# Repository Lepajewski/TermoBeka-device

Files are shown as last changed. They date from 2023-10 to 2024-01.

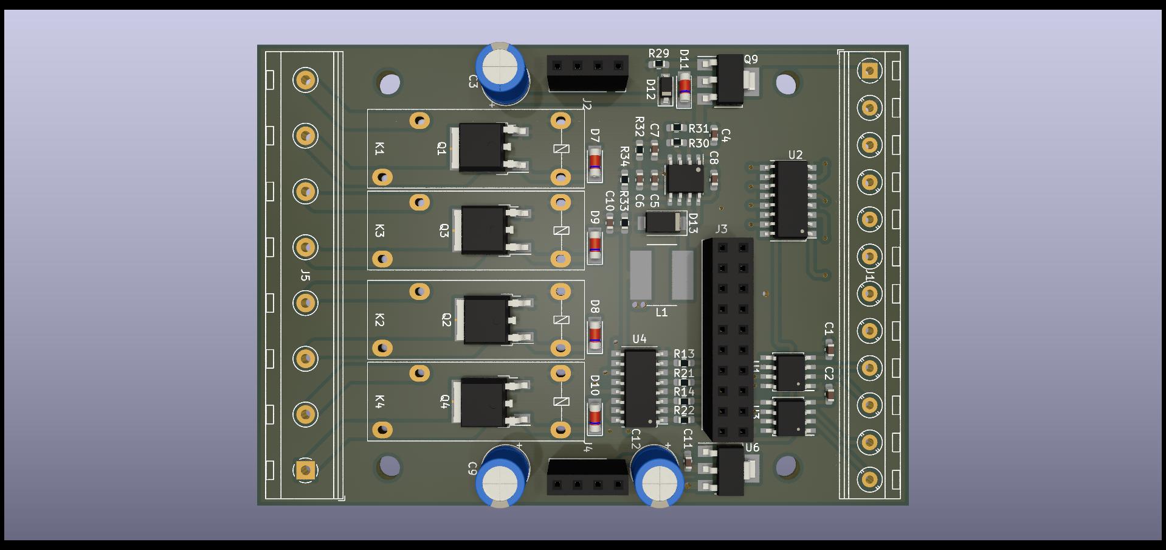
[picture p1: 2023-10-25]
doc/HW/RelayBoard/TermoPLC_RelayBoard.jpg

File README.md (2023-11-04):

# TermoBeka-device

## Installation Guide

### Windows 10

1. Install [Docker Desktop](https://www.docker.com/products/docker-desktop/). Do not check *Enable integration with my default WSL distro* in settings.

2. Install [Remote Development](https://marketplace.visualstudio.com/items?itemName=ms-vscode-remote.vscode-remote-extensionpack) extenstion in VS Code. Do not check *Execute In WSL* in DEV Container: settings

3. Install [Ubuntu 20.04 LTS](https://apps.microsoft.com/store/detail/ubuntu-20046-lts/9MTTCL66CPXJ)
> Note: kernel version must be higher than `5.10.60.1`, check by `uname -a` on Ubuntu or by `wsl --version` on CMD

4. Make Ubuntu default WSL in CMD: `wsl -l -v` and `wsl --set-default Ubuntu-20.04`

5. Install usbipd in CMD: `winget install usbipd`

6. In Ubuntu run commands:
- `sudo apt-get update && sudo apt-get -qqy upgrade`
- `sudo apt install linux-tools-virtual hwdata`
- `sudo update-alternatives --install /usr/local/bin/usbip usbip $(command -v ls /usr/lib/linux-tools/*/usbip | tail -n1) 20`
- `sudo udevadm control --reload`
- `sudo service udev restart`

7. Plug board to computer (on devkit use UART MicroUSB port).

8. In CMD run:
- `usbipd wsl list`
- `usbipd wsl attach --busid id-id`

Now device should be listed as attached:
- `usbipd wsl list`

> Note: more advanced instructions for steps 6-8 available [here](https://github.com/dorssel/usbipd-win/wiki/WSL-support)

9. Open folder in Dev Container:
- first use: `F1` + `Dev Containers: Rebuild Without Cache and Reopen in Container`
- further use: `F1` + `Dev Containers: Reopen in Container`

10. Wait for PlatrofmIO to setup. Reload window after setup.

11. Finally run in terminal:
- `make all`

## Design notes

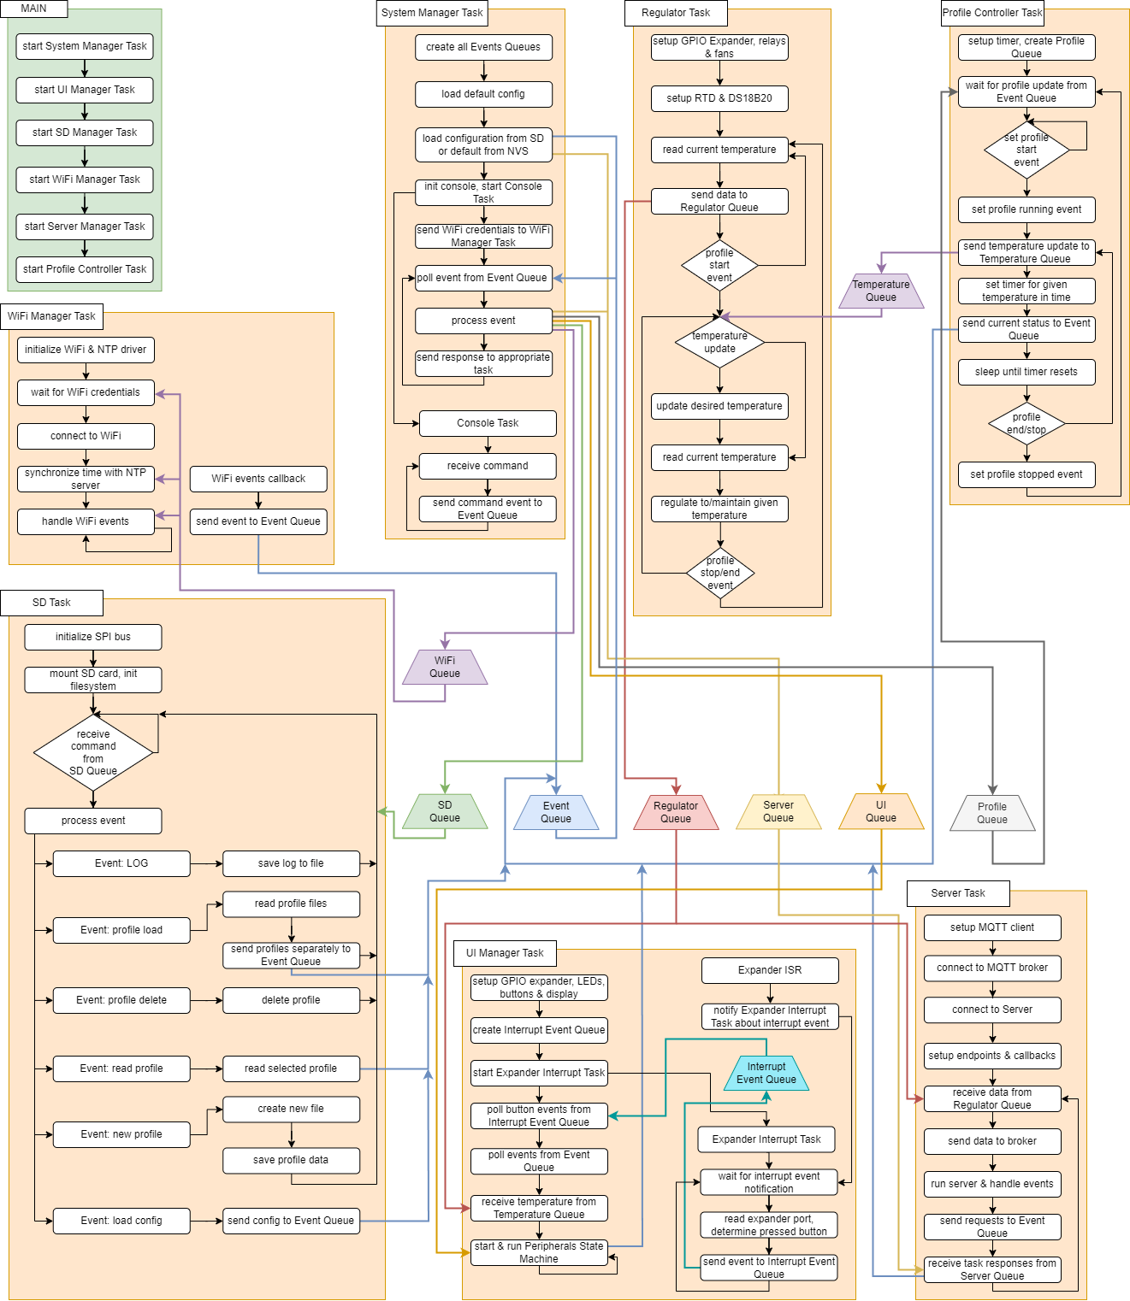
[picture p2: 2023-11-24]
doc/SW/TermoBeka_architecture.png

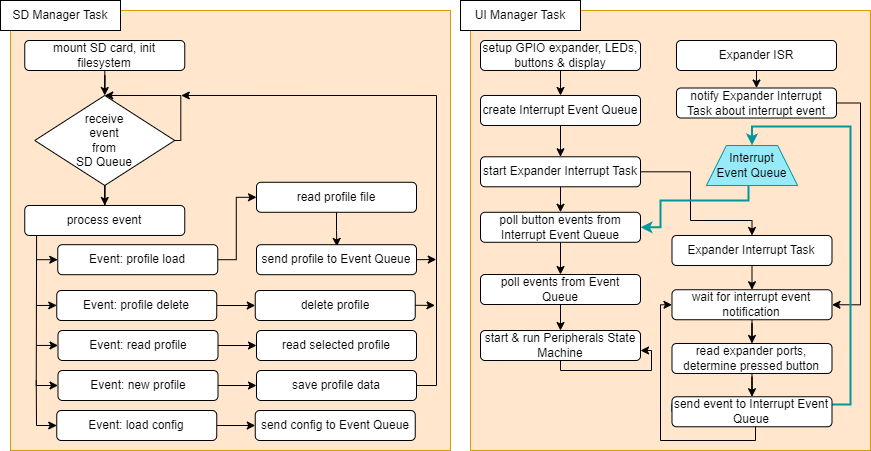
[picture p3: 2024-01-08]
doc/SW/sd_ui.png

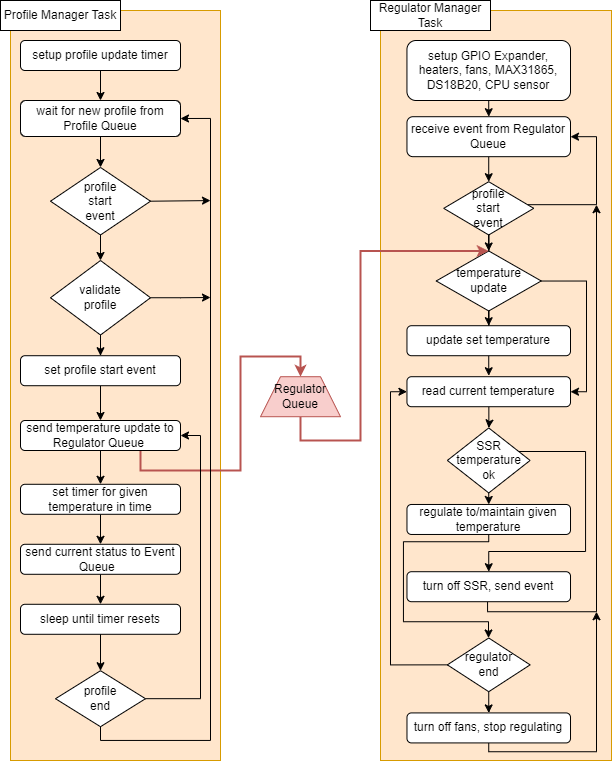
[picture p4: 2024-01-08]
doc/SW/profile_regulator.png

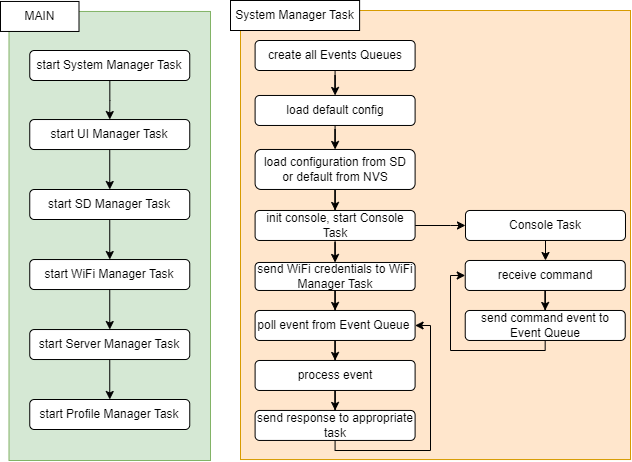
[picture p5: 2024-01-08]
doc/SW/main_sysmgr.png

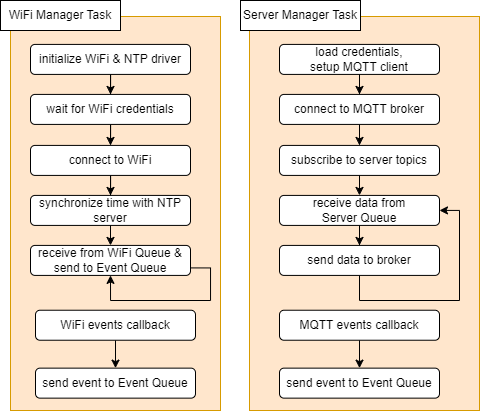
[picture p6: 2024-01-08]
doc/SW/wifi_server.png

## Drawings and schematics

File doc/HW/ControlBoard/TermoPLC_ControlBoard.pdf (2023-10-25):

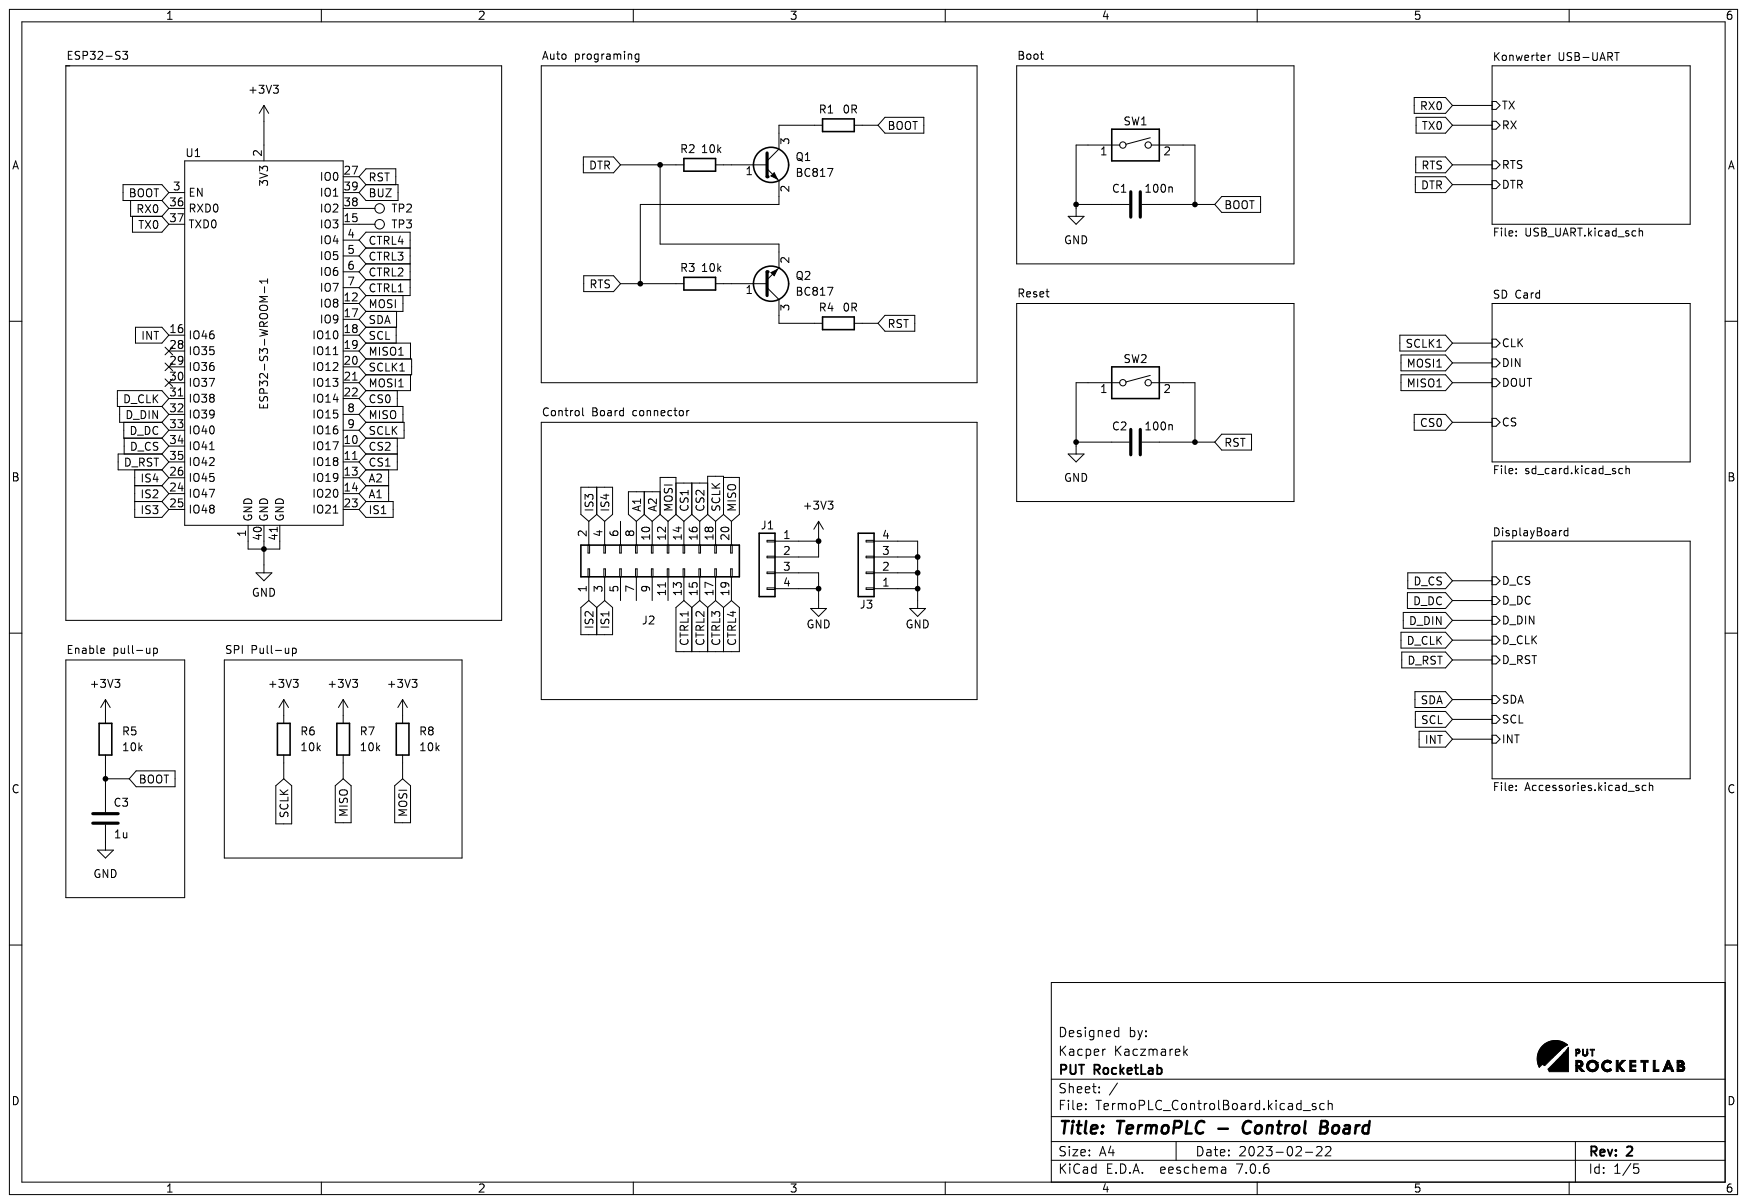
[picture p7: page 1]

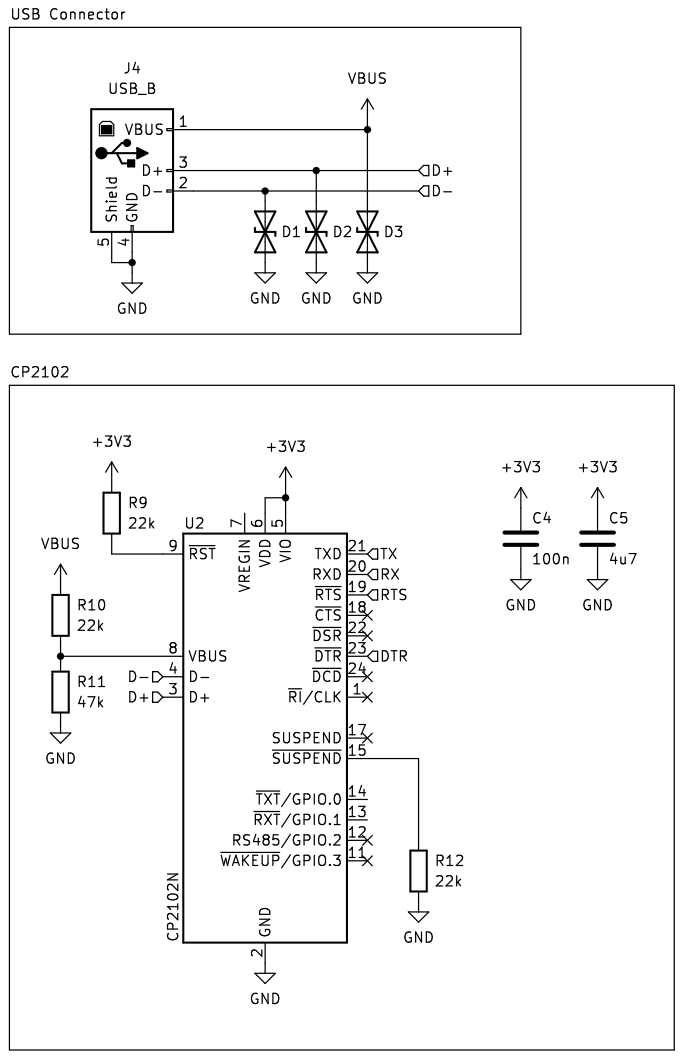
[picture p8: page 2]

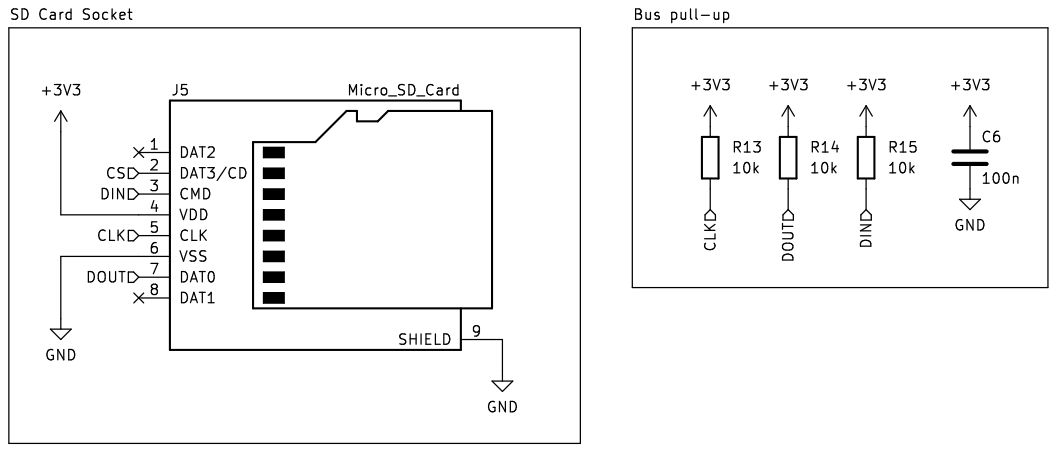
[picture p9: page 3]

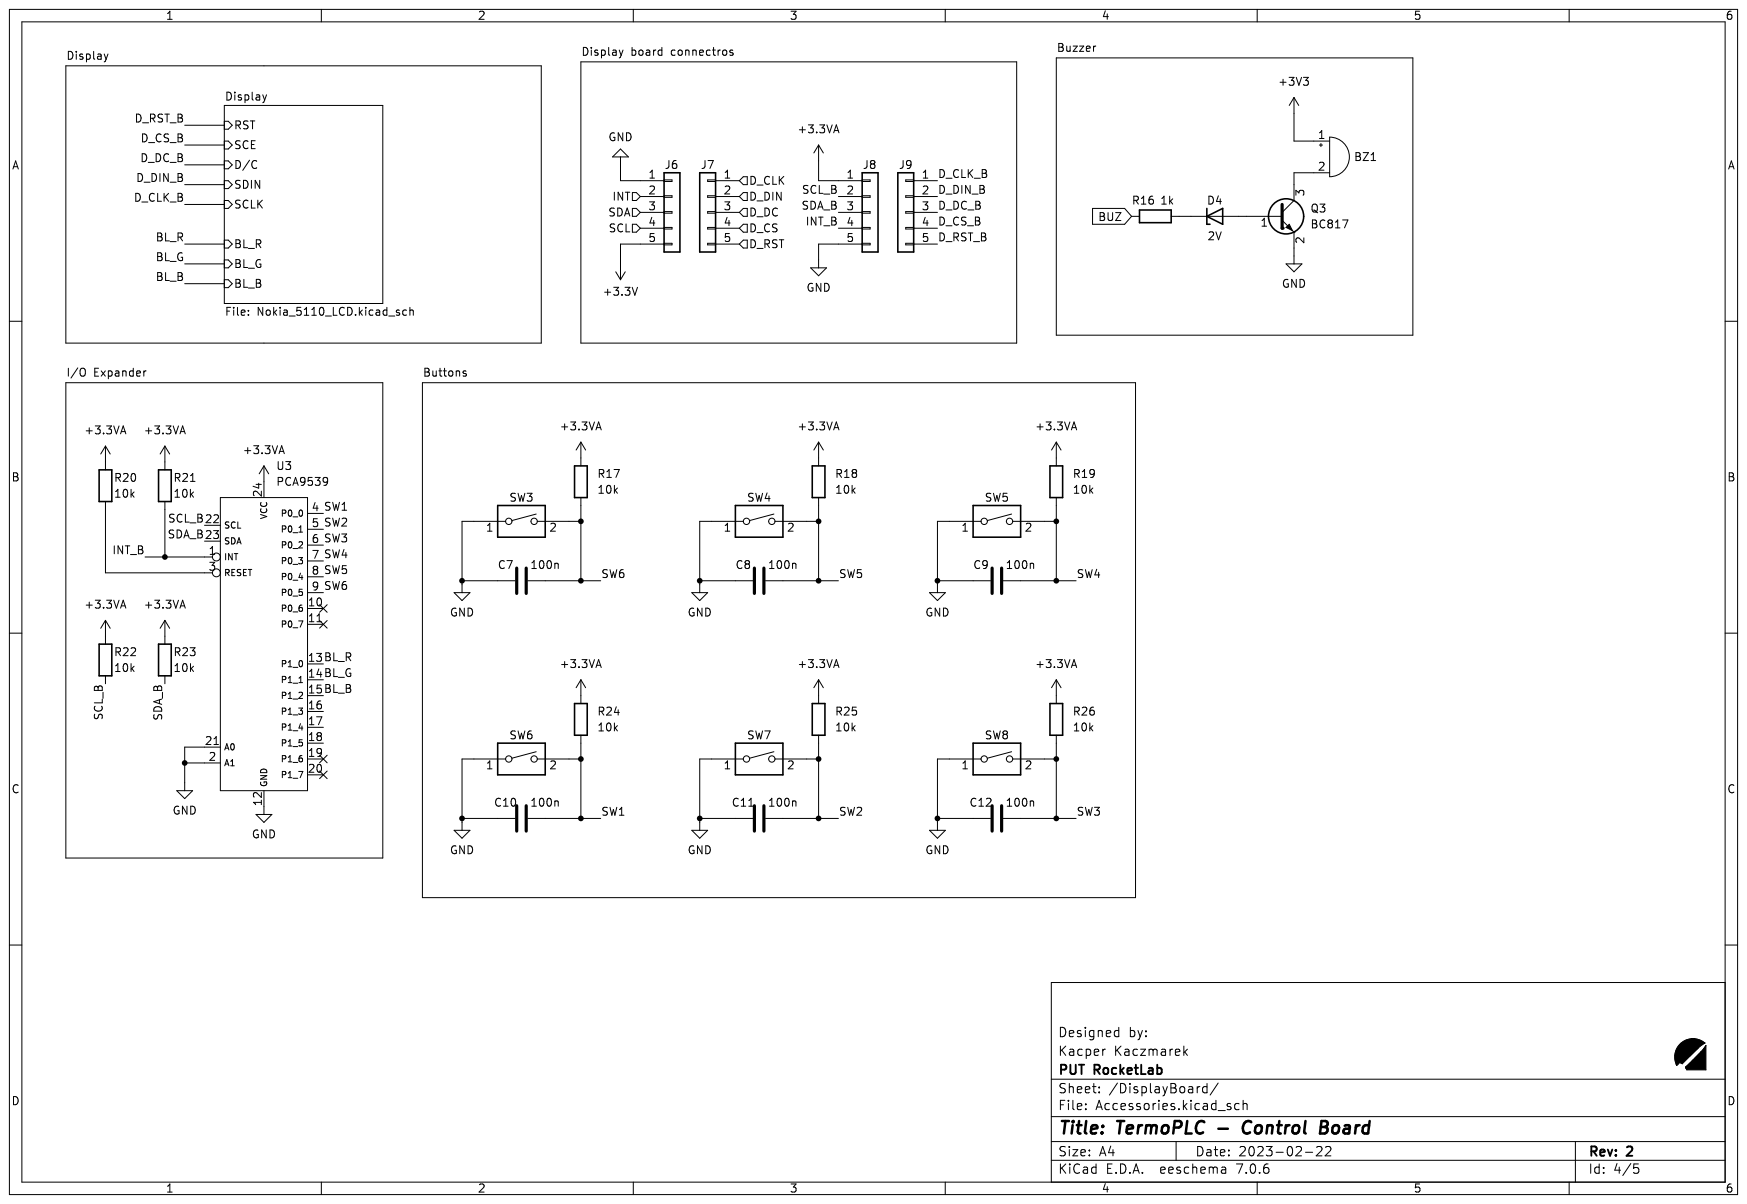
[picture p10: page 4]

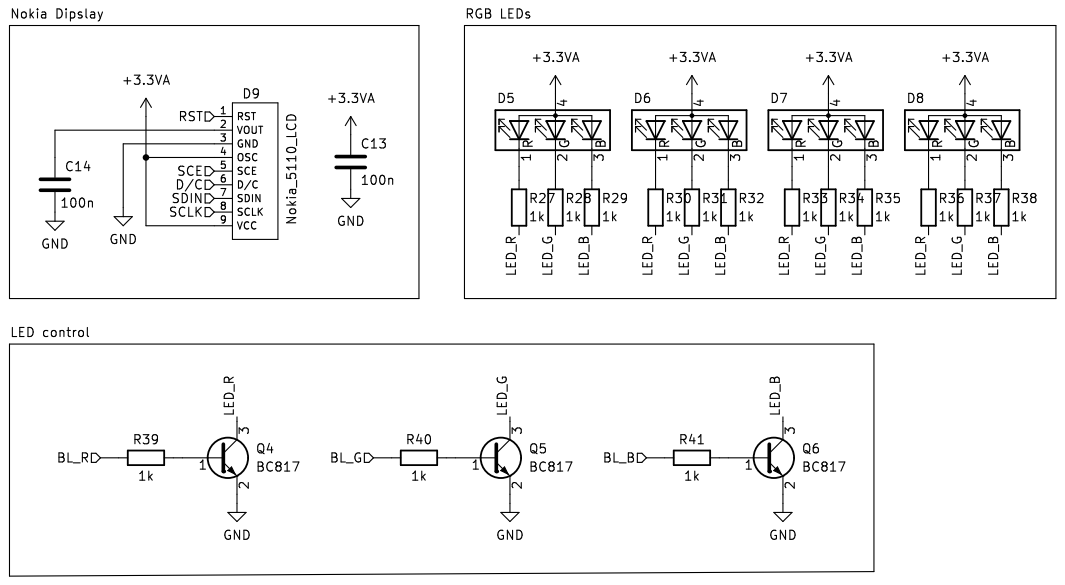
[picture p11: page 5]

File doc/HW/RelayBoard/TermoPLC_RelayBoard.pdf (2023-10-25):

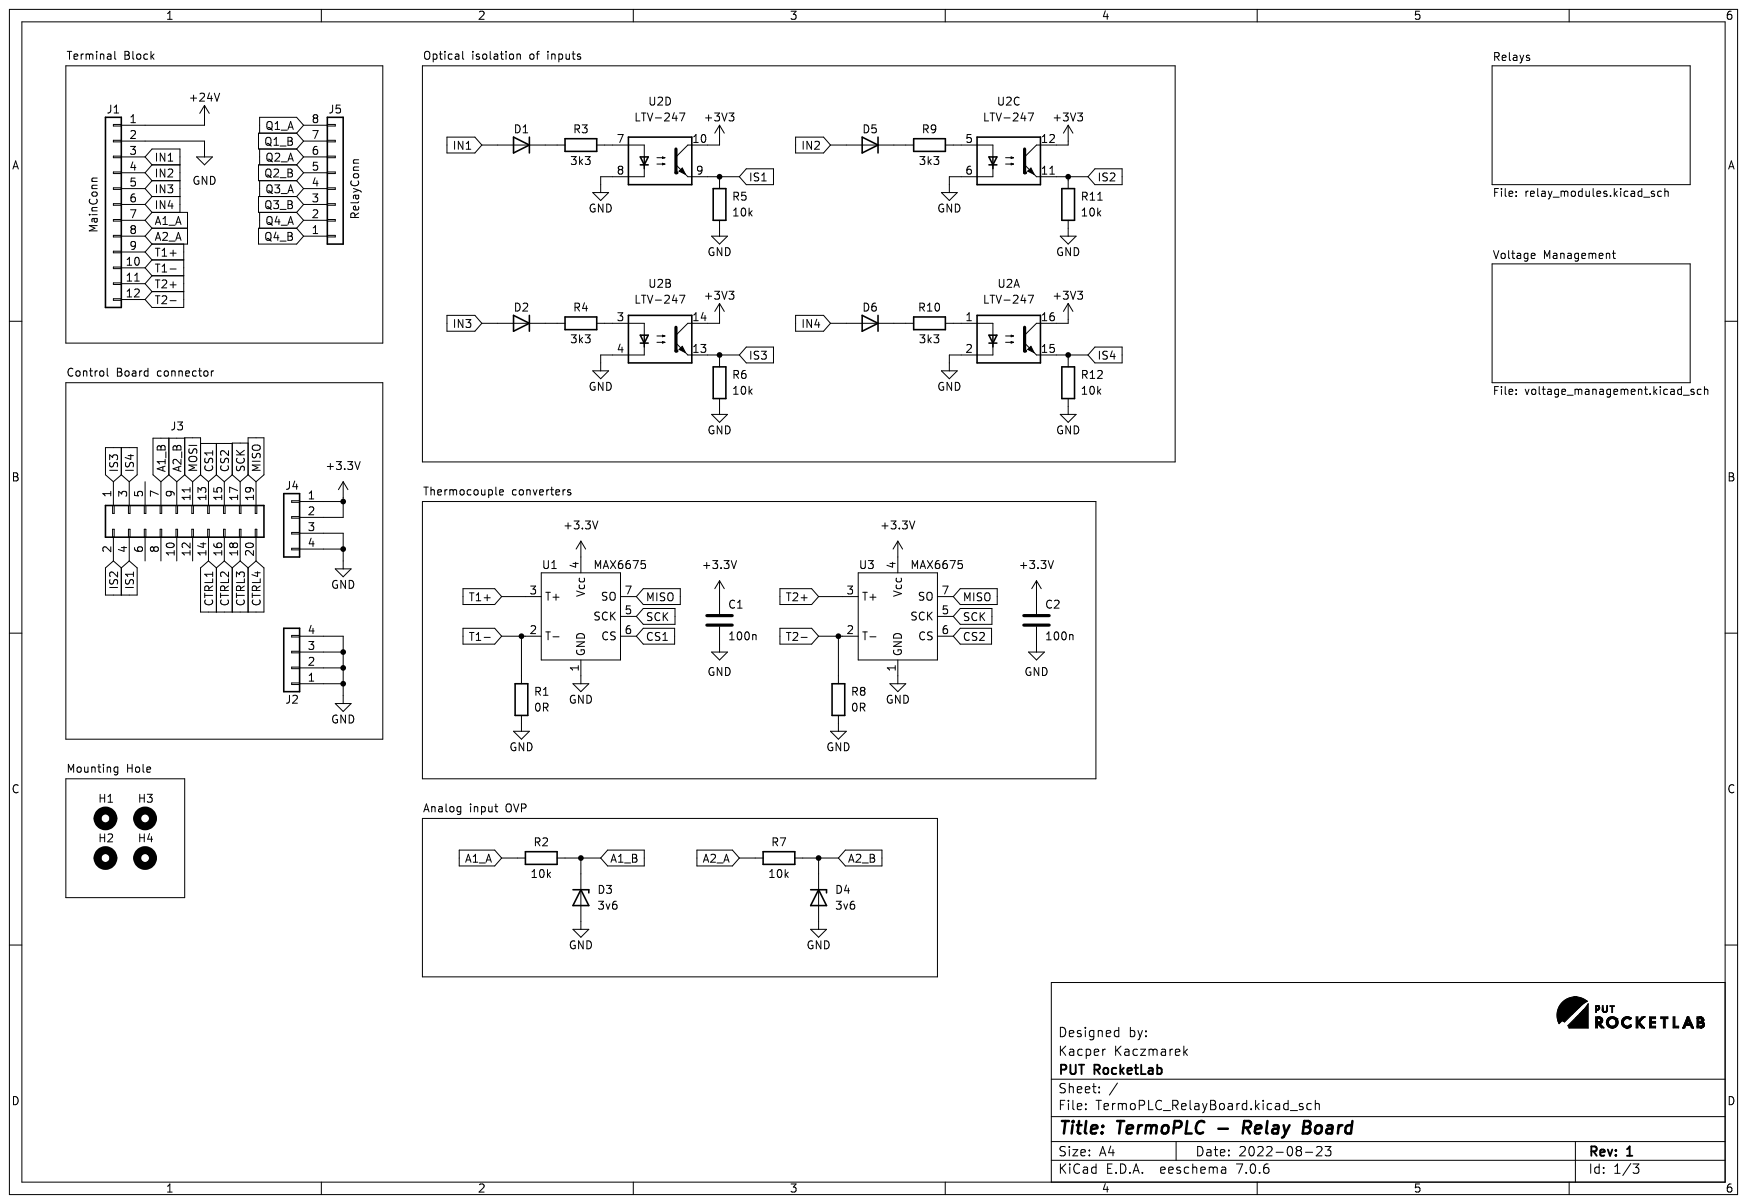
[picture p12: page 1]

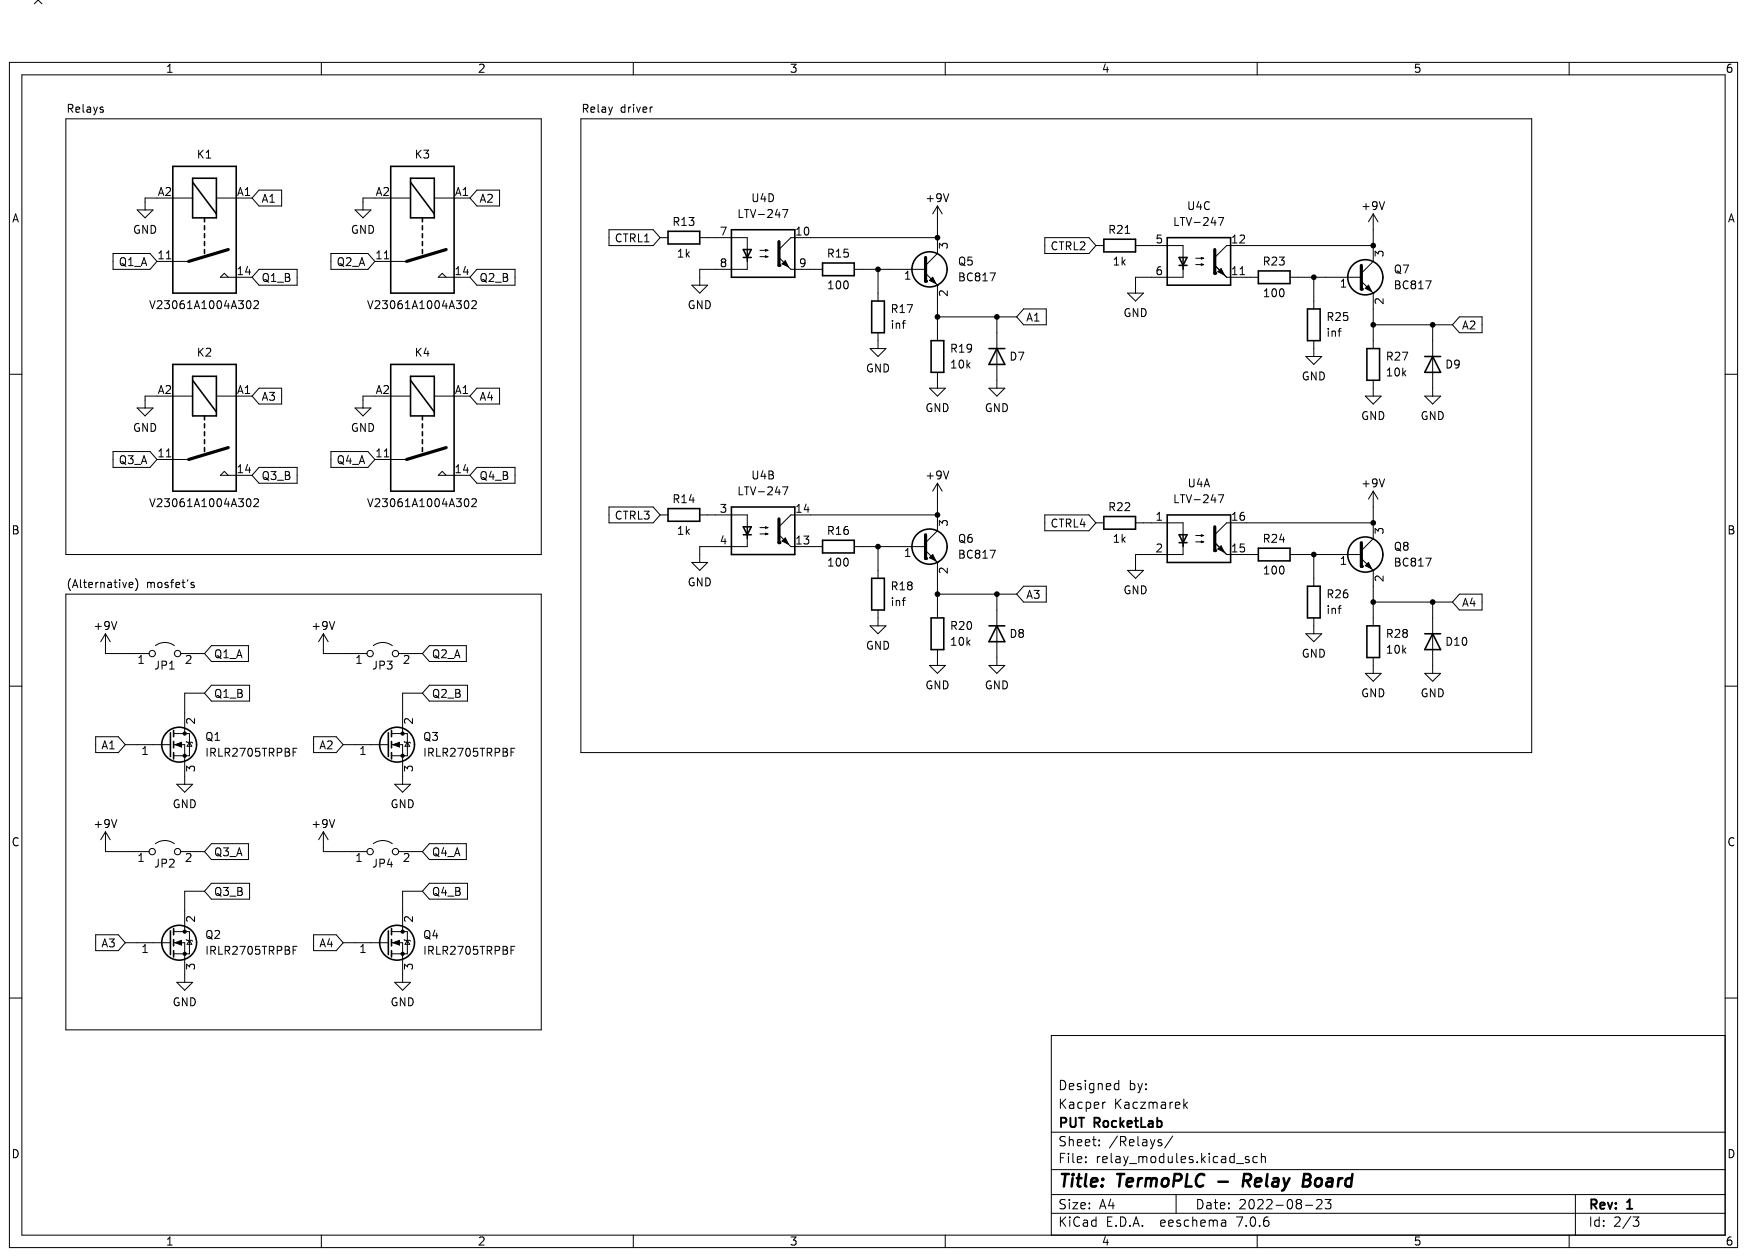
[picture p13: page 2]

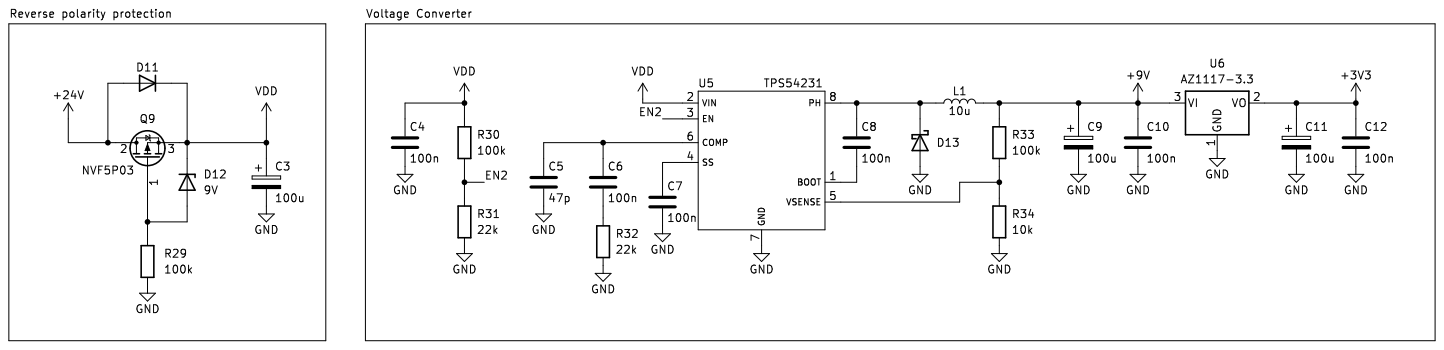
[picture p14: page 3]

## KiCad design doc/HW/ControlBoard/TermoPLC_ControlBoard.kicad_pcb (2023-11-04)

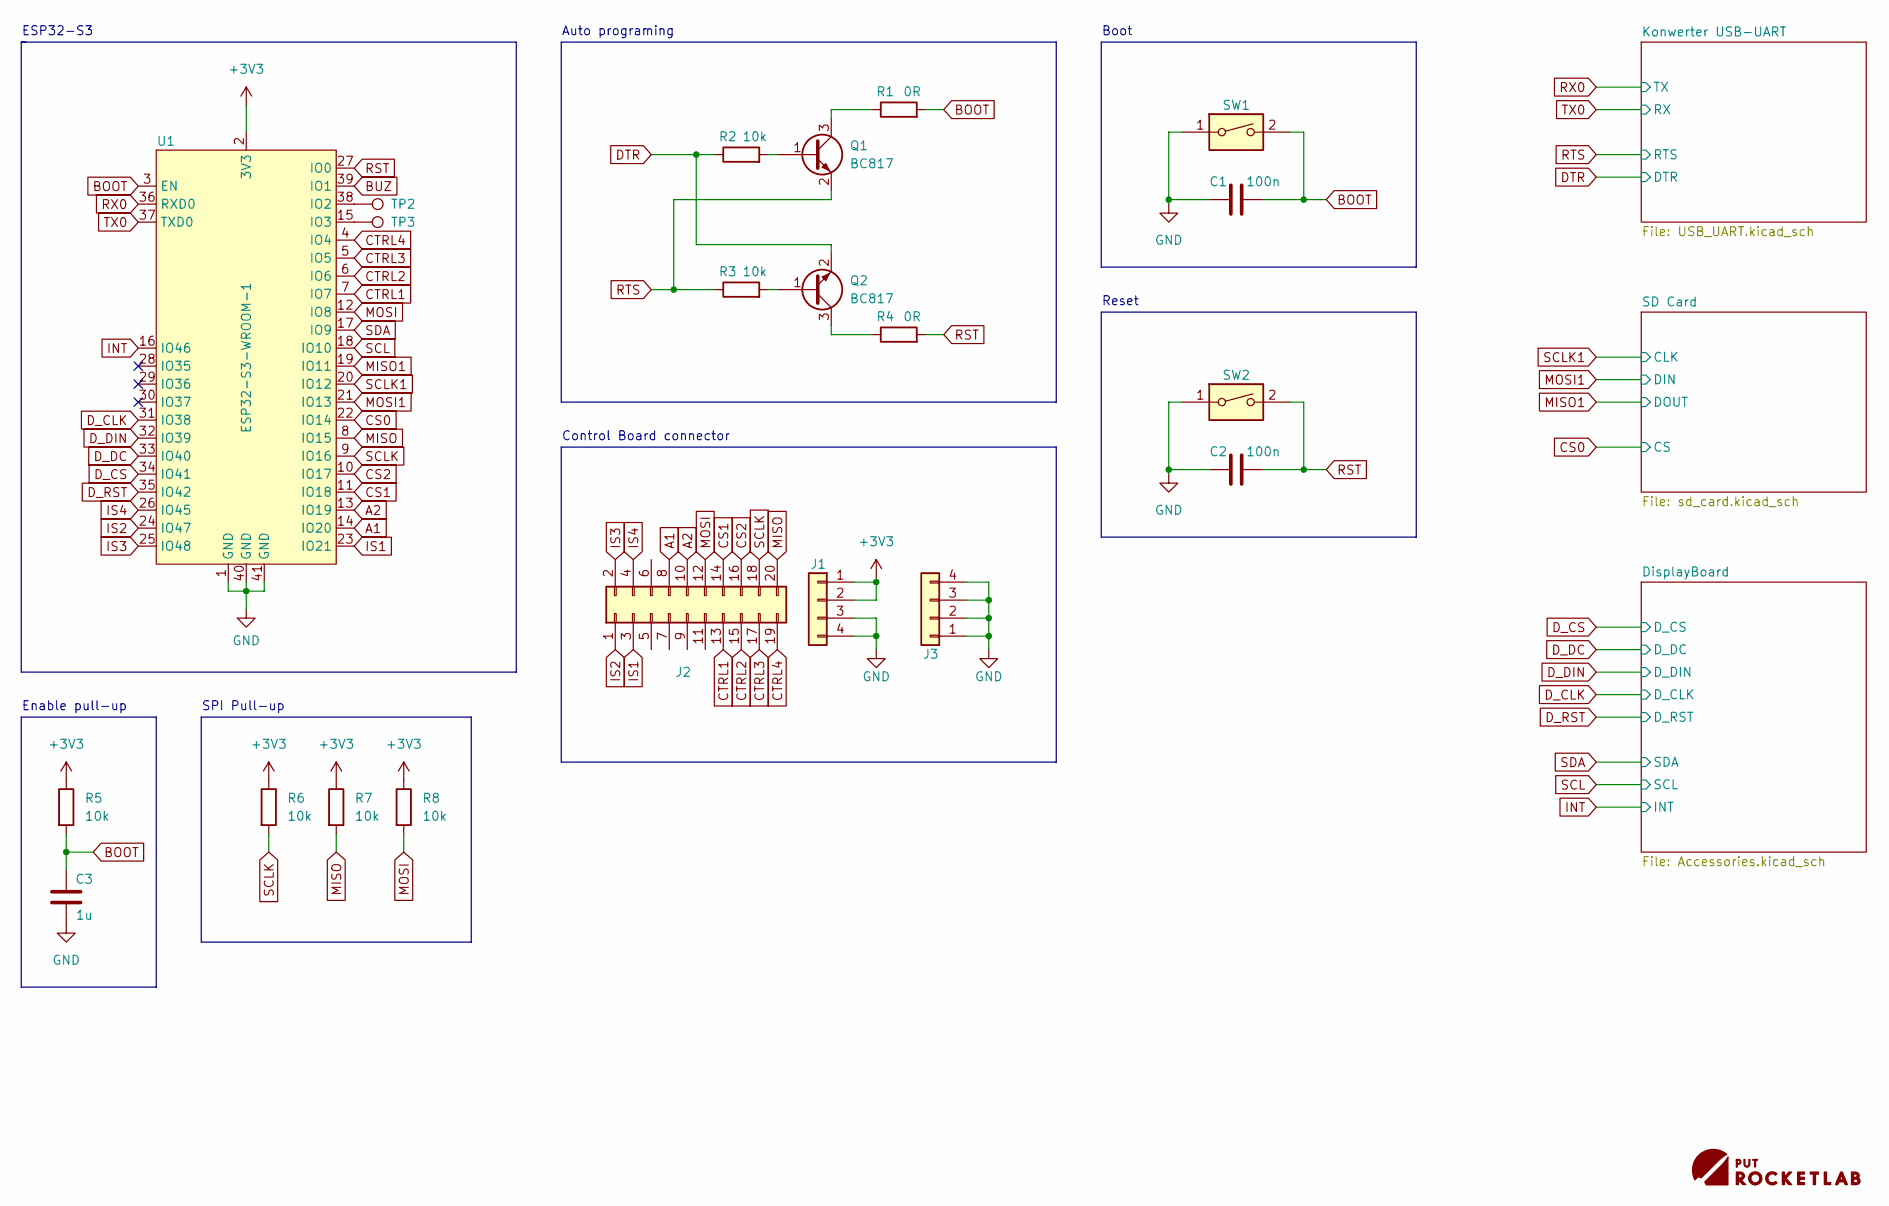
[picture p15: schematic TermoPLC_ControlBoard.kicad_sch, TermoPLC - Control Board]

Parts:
C1, C2: 100n; C_0603_1608Metric_Pad1.08x0.95mm_HandSolder
C3: 1u; C_1206_3216Metric_Pad1.33x1.80mm_HandSolder
G1: PutRocketLab_logo_large; PutRocketlab_logo_2_h4mm
J1: Conn_01x04; PinSocket_1x04_P2.54mm_Vertical_SMD_Pin1Left
J2: Conn_02x10_Odd_Even; PinSocket_2x10_P2.54mm_Vertical_SMD
J3: Conn_01x04; PinSocket_1x04_P2.54mm_Vertical_SMD_Pin1Right
Q1, Q2: BC817; SOT-23
R1, R4: 0R; R_0603_1608Metric_Pad0.98x0.95mm_HandSolder
R2, R3, R5, R6, R7, R8: 10k; R_0603_1608Metric_Pad0.98x0.95mm_HandSolder
SW1, SW2: SW_DIP_x01; SW_SPST_FSMSM
TP2, TP3: SolderPoint; TestPoint_Pad_D1.0mm
U1: ESP32-S3-WROOM-1

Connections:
A1: J2.8, U1.14 (IO20)
A2: J2.10, U1.13 (IO19)
BOOT: C1.2, C3.2, R1.2, R5.2, SW1.2, U1.3 (EN)
BUZ: U1.39 (IO1); also elsewhere on the board
CS0: U1.22 (IO14); also elsewhere on the board
CS1: J2.14, U1.11 (IO18)
CS2: J2.16, U1.10 (IO17)
CTRL1: J2.13, U1.7 (IO7)
CTRL2: J2.15, U1.6 (IO6)
CTRL3: J2.17, U1.5 (IO5)
CTRL4: J2.19, U1.4 (IO4)
DTR: Q2.2 (E), R2.1; also elsewhere on the board
D_CLK: U1.31 (IO38); also elsewhere on the board
D_CS: U1.34 (IO41); also elsewhere on the board
D_DC: U1.33 (IO40); also elsewhere on the board
D_DIN: U1.32 (IO39); also elsewhere on the board
D_RST: U1.35 (IO42); also elsewhere on the board
GND: C1.1, C2.1, C3.1, J1.3, J1.4, J3.1, J3.2, J3.3, J3.4, SW1.1, SW2.1, U1.1 (GND), U1.40 (GND), U1.41 (GND); also elsewhere on the board
INT: U1.16 (IO46); also elsewhere on the board
IS1: J2.3, U1.23 (IO21)
IS2: J2.1, U1.24 (IO47)
IS3: J2.2, U1.25 (IO48)
IS4: J2.4, U1.26 (IO45)
MISO: J2.20, R7.2, U1.8 (IO15)
MISO1: U1.19 (IO11); also elsewhere on the board
MOSI: J2.12, R8.2, U1.12 (IO8)
MOSI1: U1.21 (IO13); also elsewhere on the board
unnamed: Q1.1 (B), R2.2
unnamed: Q1.3 (C), R1.1
unnamed: Q2.1 (B), R3.2
unnamed: Q2.3 (C), R4.1
unnamed: TP2.1, U1.38 (IO2)
unnamed: TP3.1, U1.15 (IO3)
RST: C2.2, R4.2, SW2.2, U1.27 (IO0)
RTS: Q1.2 (E), R3.1; also elsewhere on the board
RX0: U1.36 (RXD0); also elsewhere on the board
SCL: U1.18 (IO10); also elsewhere on the board
SCLK: J2.18, R6.2, U1.9 (IO16)
SCLK1: U1.20 (IO12); also elsewhere on the board
SDA: U1.17 (IO9); also elsewhere on the board
TX0: U1.37 (TXD0); also elsewhere on the board

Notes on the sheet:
ESP32-S3
Enable pull-up
Auto programing
Control Board connector
Reset
SPI Pull-up
Boot

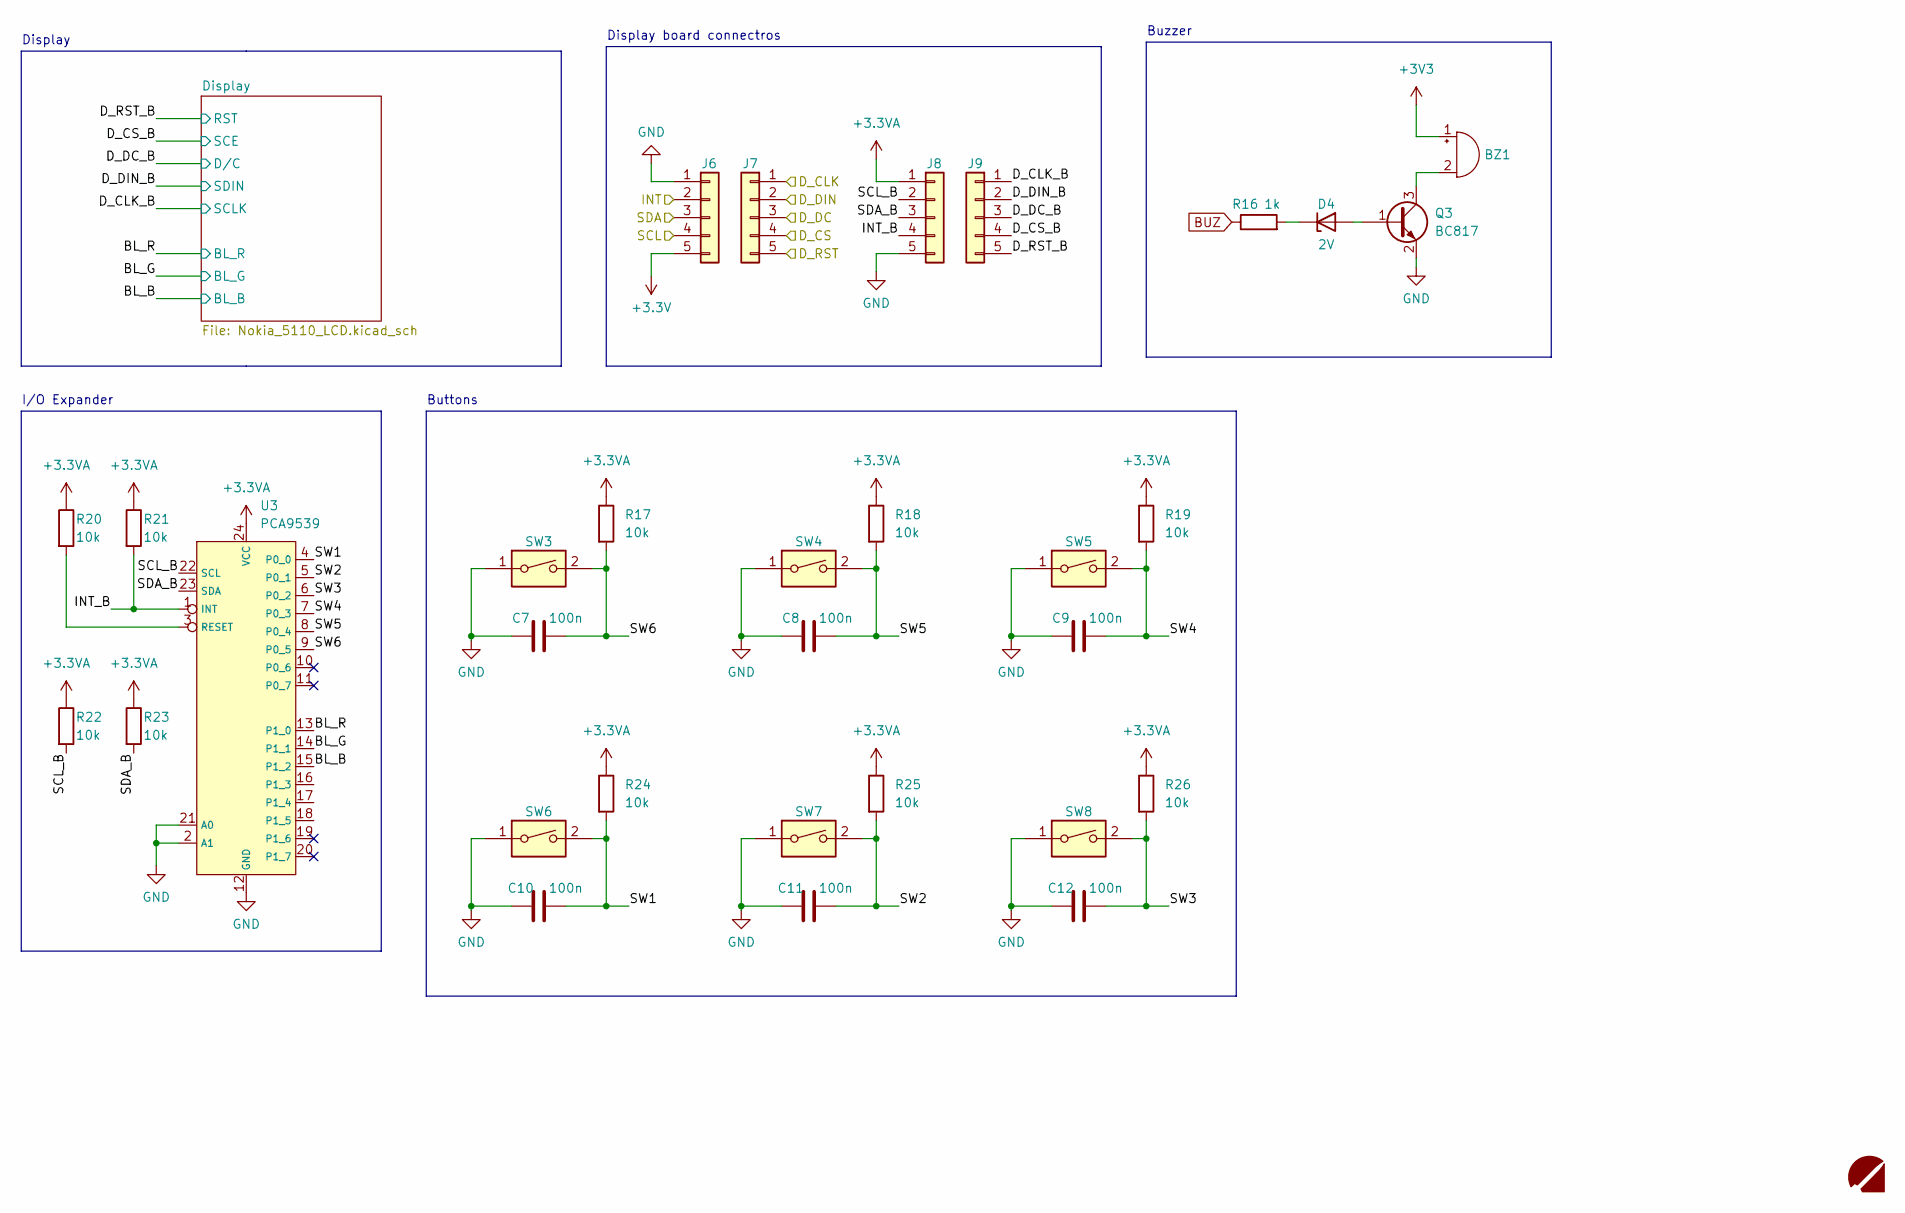
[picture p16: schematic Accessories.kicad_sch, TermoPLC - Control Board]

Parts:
BZ1: Buzzer; Buzzer_fi10mm_P5mm
C7, C8, C9, C10, C11, C12: 100n; C_0603_1608Metric_Pad1.08x0.95mm_HandSolder
D4: 2V; D_SOD-123
G2: PutRocketLab_logo_small; PutRocketlab_logo_1_5x5mm
J6: Conn_01x05; PinSocket_1x05_P2.54mm_Vertical_SMD_Pin1Right
J7: Conn_01x05; PinSocket_1x05_P2.54mm_Vertical_SMD_Pin1Left
J8: Conn_01x05; PinHeader_1x05_P2.54mm_Vertical_SMD_Pin1Right
J9: Conn_01x05; PinHeader_1x05_P2.54mm_Vertical_SMD_Pin1Left
Q3: BC817; SOT-23
R16: 1k; R_0603_1608Metric_Pad0.98x0.95mm_HandSolder
R17, R18, R19, R20, R21, R22, R23, R24, R25, R26: 10k; R_0603_1608Metric_Pad0.98x0.95mm_HandSolder
SW3, SW4, SW5, SW6, SW7, SW8: SW_DIP_x01; SW_SPST_PTS645
U3: PCA9539; TSSOP-24_4.4x7.8mm_P0.65mm

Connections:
+3.3VA: J8.1, R17.1, R18.1, R19.1, R20.1, R21.1, R22.1, R23.1, R24.1, R25.1, R26.1, U3.24 (VCC); also elsewhere on the board
/DisplayBoard/BL_B: U3.15 (P1_2); also elsewhere on the board
/DisplayBoard/BL_G: U3.14 (P1_1); also elsewhere on the board
/DisplayBoard/BL_R: U3.13 (P1_0); also elsewhere on the board
/DisplayBoard/D_CLK_B: J9.1; also elsewhere on the board
/DisplayBoard/D_CS_B: J9.4; also elsewhere on the board
/DisplayBoard/D_DC_B: J9.3; also elsewhere on the board
/DisplayBoard/D_DIN_B: J9.2; also elsewhere on the board
/DisplayBoard/D_RST_B: J9.5; also elsewhere on the board
/DisplayBoard/INT_B: J8.4, R21.2, U3.1 (INT)
/DisplayBoard/SCL_B: J8.2, R22.2, U3.22 (SCL)
/DisplayBoard/SDA_B: J8.3, R23.2, U3.23 (SDA)
/DisplayBoard/SW1: C10.2, R24.2, SW6.2, U3.4 (P0_0)
/DisplayBoard/SW2: C11.2, R25.2, SW7.2, U3.5 (P0_1)
/DisplayBoard/SW3: C12.2, R26.2, SW8.2, U3.6 (P0_2)
/DisplayBoard/SW4: C9.2, R19.2, SW5.2, U3.7 (P0_3)
/DisplayBoard/SW5: C8.2, R18.2, SW4.2, U3.8 (P0_4)
/DisplayBoard/SW6: C7.2, R17.2, SW3.2, U3.9 (P0_5)
BUZ: R16.1; also elsewhere on the board
D_CLK: J7.1; also elsewhere on the board
D_CS: J7.4; also elsewhere on the board
D_DC: J7.3; also elsewhere on the board
D_DIN: J7.2; also elsewhere on the board
D_RST: J7.5; also elsewhere on the board
GND: C7.1, C8.1, C9.1, C10.1, C11.1, C12.1, J6.1, J8.5, Q3.2 (E), SW3.1, SW4.1, SW5.1, SW6.1, SW7.1, SW8.1, U3.2 (A1), U3.12 (GND), U3.21 (A0); also elsewhere on the board
INT: J6.2; also elsewhere on the board
unnamed: BZ1.2 (+), Q3.3 (C)
unnamed: D4.1 (K), R16.2
unnamed: D4.2 (A), Q3.1 (B)
unnamed: R20.2, U3.3 (RESET)
SCL: J6.4; also elsewhere on the board
SDA: J6.3; also elsewhere on the board

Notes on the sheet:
Display board connectros
Buttons
Display
I/O Expander
Buzzer

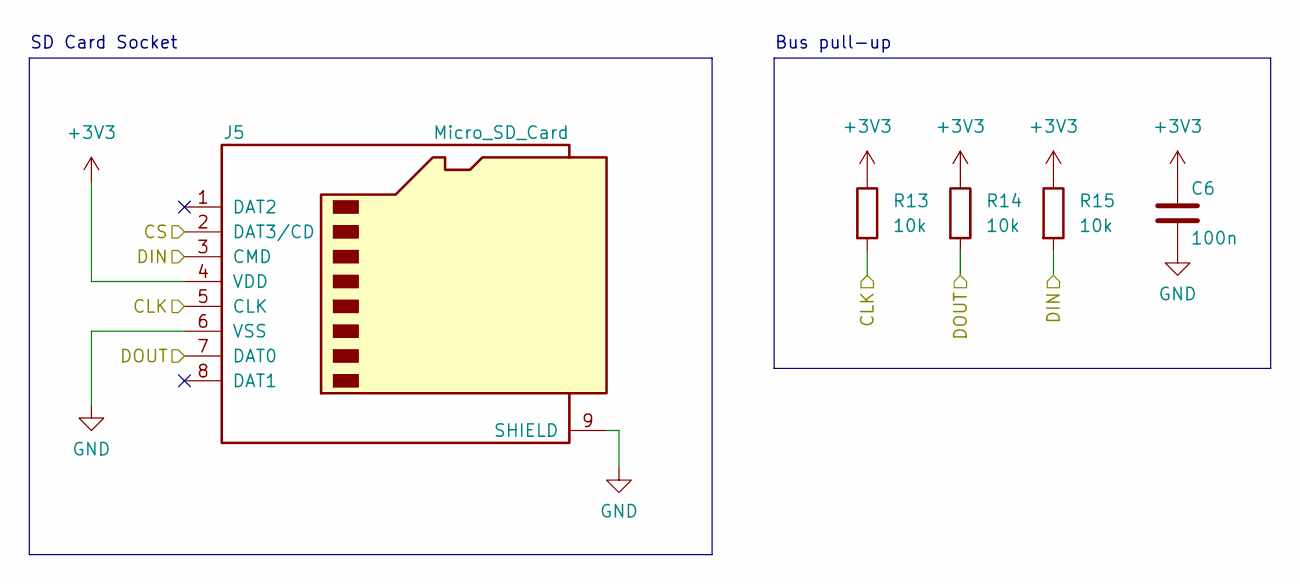
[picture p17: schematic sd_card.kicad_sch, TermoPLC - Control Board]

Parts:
C6: 100n; C_0603_1608Metric_Pad1.08x0.95mm_HandSolder
J5: Micro_SD_Card; microSD_HC_Hirose_DM3D-SF
R13, R14, R15: 10k; R_0603_1608Metric_Pad0.98x0.95mm_HandSolder

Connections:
CS0: J5.2 (DAT3/CD); also elsewhere on the board
GND: C6.1, J5.6 (VSS), J5.9 (SHIELD); also elsewhere on the board
MISO1: J5.7 (DAT0), R14.2; also elsewhere on the board
MOSI1: J5.3 (CMD), R15.2; also elsewhere on the board
SCLK1: J5.5 (CLK), R13.2; also elsewhere on the board

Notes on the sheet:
SD Card Socket
Bus pull-up

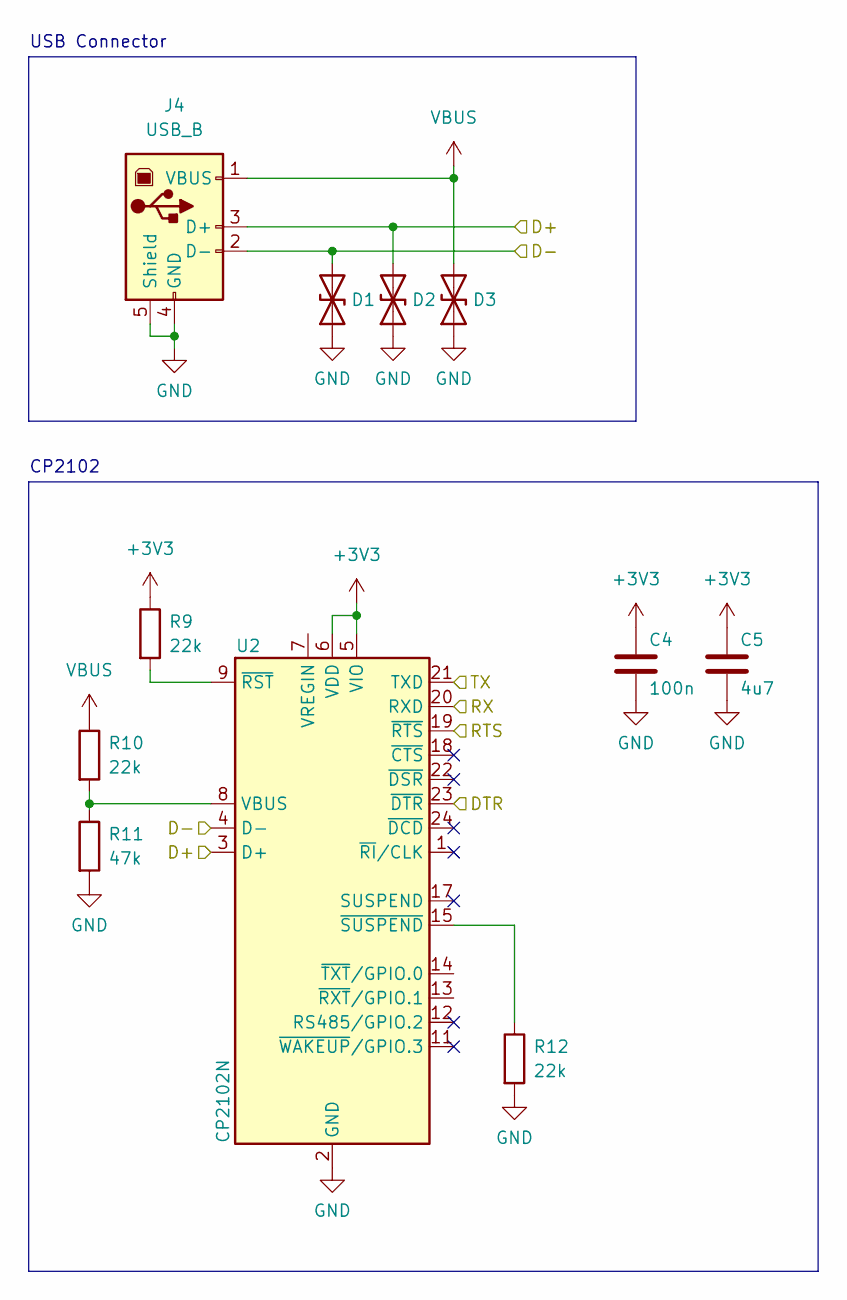
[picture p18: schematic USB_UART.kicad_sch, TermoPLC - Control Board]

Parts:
C4: 100n; C_0603_1608Metric_Pad1.08x0.95mm_HandSolder
C5: 4u7; CP_EIA-3216-18_Kemet-A_Pad1.58x1.35mm_HandSolder
D1, D2, D3: D_TVS; D_SOD-923
J4: USB_B; USB_B_OST_USB-B1HSxx_Horizontal
R9, R10, R12: 22k; R_0603_1608Metric_Pad0.98x0.95mm_HandSolder
R11: 47k; R_0603_1608Metric_Pad0.98x0.95mm_HandSolder
U2: CP2102N; QFN-24-1EP_4x4mm_P0.5mm_EP2.6x2.6mm

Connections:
/Konwerter USB-UART/D+: D2.2 (A2), J4.3 (D+), U2.3 (D+)
/Konwerter USB-UART/D-: D1.2 (A2), J4.2 (D-), U2.4 (D-)
DTR: U2.23 (~DTR); also elsewhere on the board
GND: C4.1, C5.2, D1.1 (A1), D2.1 (A1), D3.1 (A1), J4.4 (GND), J4.5 (Shield), R11.2, R12.2, U2.2 (GND), U2.25 (GND); also elsewhere on the board
unnamed: R9.2, U2.9 (~RST)
unnamed: R10.2, R11.1, U2.8 (VBUS)
unnamed: R12.1, U2.15 (~SUSPEND)
RTS: U2.19 (~RTS); also elsewhere on the board
RX0: U2.21 (TXD); also elsewhere on the board
TX0: U2.20 (RXD); also elsewhere on the board
VBUS: D3.2 (A2), J4.1 (VBUS), R10.1

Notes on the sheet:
USB Connector
CP2102

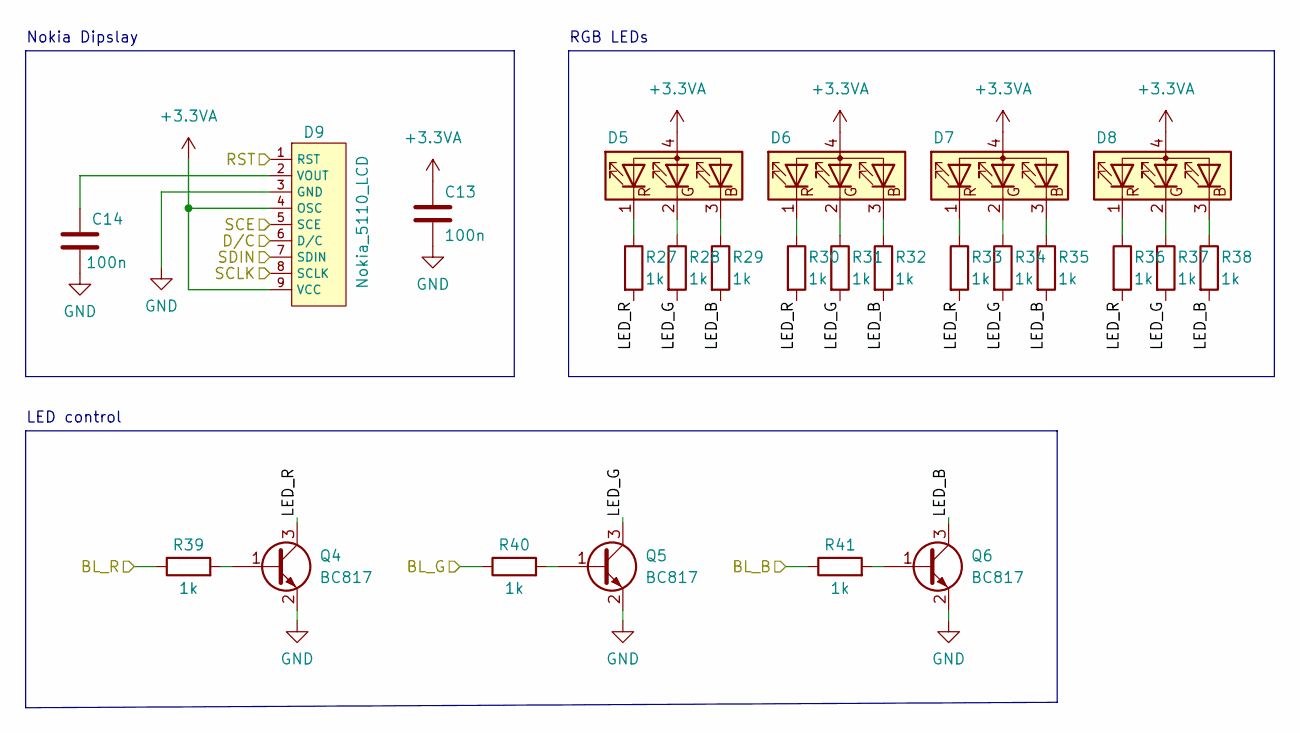
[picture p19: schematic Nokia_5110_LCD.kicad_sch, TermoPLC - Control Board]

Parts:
C13, C14: 100n; C_0603_1608Metric_Pad1.08x0.95mm_HandSolder
D5, D6, D7, D8: LED_RGBA; LED_Lumex_SML-LX0404SIUPGUSB
D9: Nokia_5110_LCD; Raw_Nokia_5110_LCD
Q4, Q5, Q6: BC817; SOT-23
R27, R28, R29, R30, R31, R32, R33, R34, R35, R36, R37, R38, R39, R40, R41: 1k; R_0603_1608Metric_Pad0.98x0.95mm_HandSolder

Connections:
+3.3VA: C13.2, D5.4 (A), D6.4 (A), D7.4 (A), D8.4 (A), D9.4 (OSC), D9.9 (VCC); also elsewhere on the board
/DisplayBoard/BL_B: R41.1; also elsewhere on the board
/DisplayBoard/BL_G: R40.1; also elsewhere on the board
/DisplayBoard/BL_R: R39.1; also elsewhere on the board
/DisplayBoard/D_CLK_B: D9.8 (SCLK); also elsewhere on the board
/DisplayBoard/D_CS_B: D9.5 (SCE); also elsewhere on the board
/DisplayBoard/D_DC_B: D9.6 (D/C); also elsewhere on the board
/DisplayBoard/D_DIN_B: D9.7 (SDIN); also elsewhere on the board
/DisplayBoard/D_RST_B: D9.1 (RST); also elsewhere on the board
/DisplayBoard/Display/LED_B: Q6.3 (C), R29.2, R32.2, R35.2, R38.2
/DisplayBoard/Display/LED_G: Q5.3 (C), R28.2, R31.2, R34.2, R37.2
/DisplayBoard/Display/LED_R: Q4.3 (C), R27.2, R30.2, R33.2, R36.2
GND: C13.1, C14.1, D9.3 (GND), Q4.2 (E), Q5.2 (E), Q6.2 (E); also elsewhere on the board
unnamed: C14.2, D9.2 (VOUT)
unnamed: D5.1 (RK), R27.1
unnamed: D5.2 (GK), R28.1
unnamed: D5.3 (BK), R29.1
unnamed: D6.1 (RK), R30.1
unnamed: D6.2 (GK), R31.1
unnamed: D6.3 (BK), R32.1
unnamed: D7.1 (RK), R33.1
unnamed: D7.2 (GK), R34.1
unnamed: D7.3 (BK), R35.1
unnamed: D8.1 (RK), R36.1
unnamed: D8.2 (GK), R37.1
unnamed: D8.3 (BK), R38.1
unnamed: Q4.1 (B), R39.2
unnamed: Q5.1 (B), R40.2
unnamed: Q6.1 (B), R41.2

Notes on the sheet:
RGB LEDs
LED control
Nokia Dipslay

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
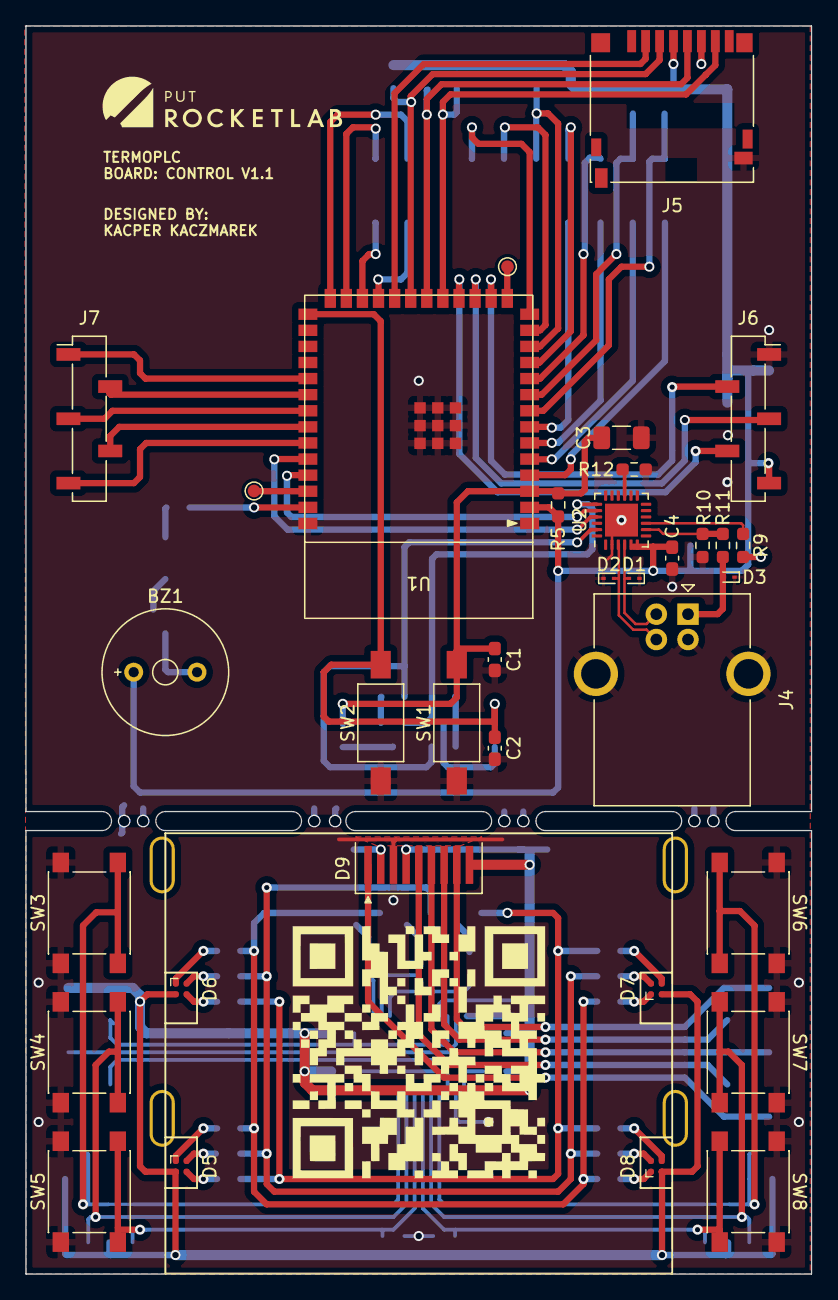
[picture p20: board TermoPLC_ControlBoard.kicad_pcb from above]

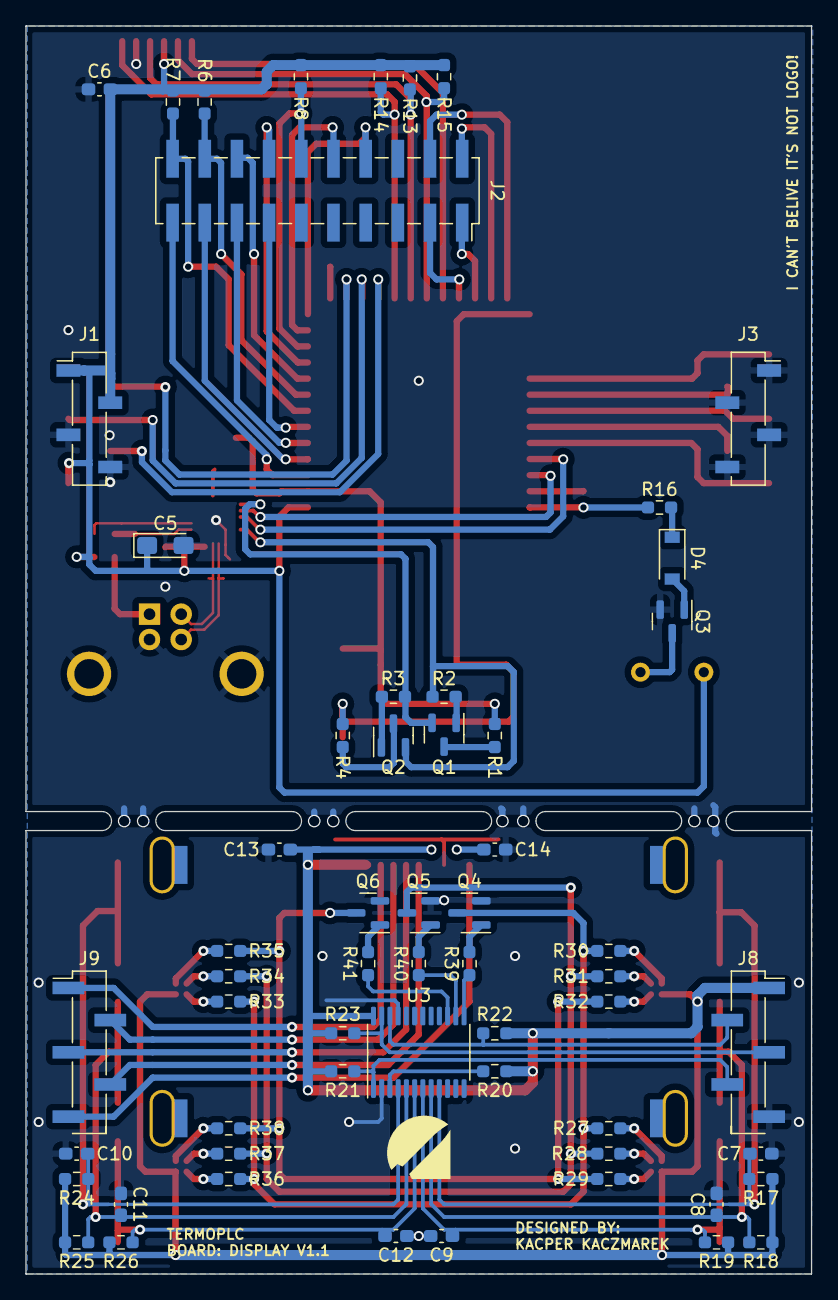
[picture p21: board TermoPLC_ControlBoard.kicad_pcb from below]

Board: 2 copper layers, 62.0 x 98.5 mm, 95 parts (60 on the bottom side), 89 nets.

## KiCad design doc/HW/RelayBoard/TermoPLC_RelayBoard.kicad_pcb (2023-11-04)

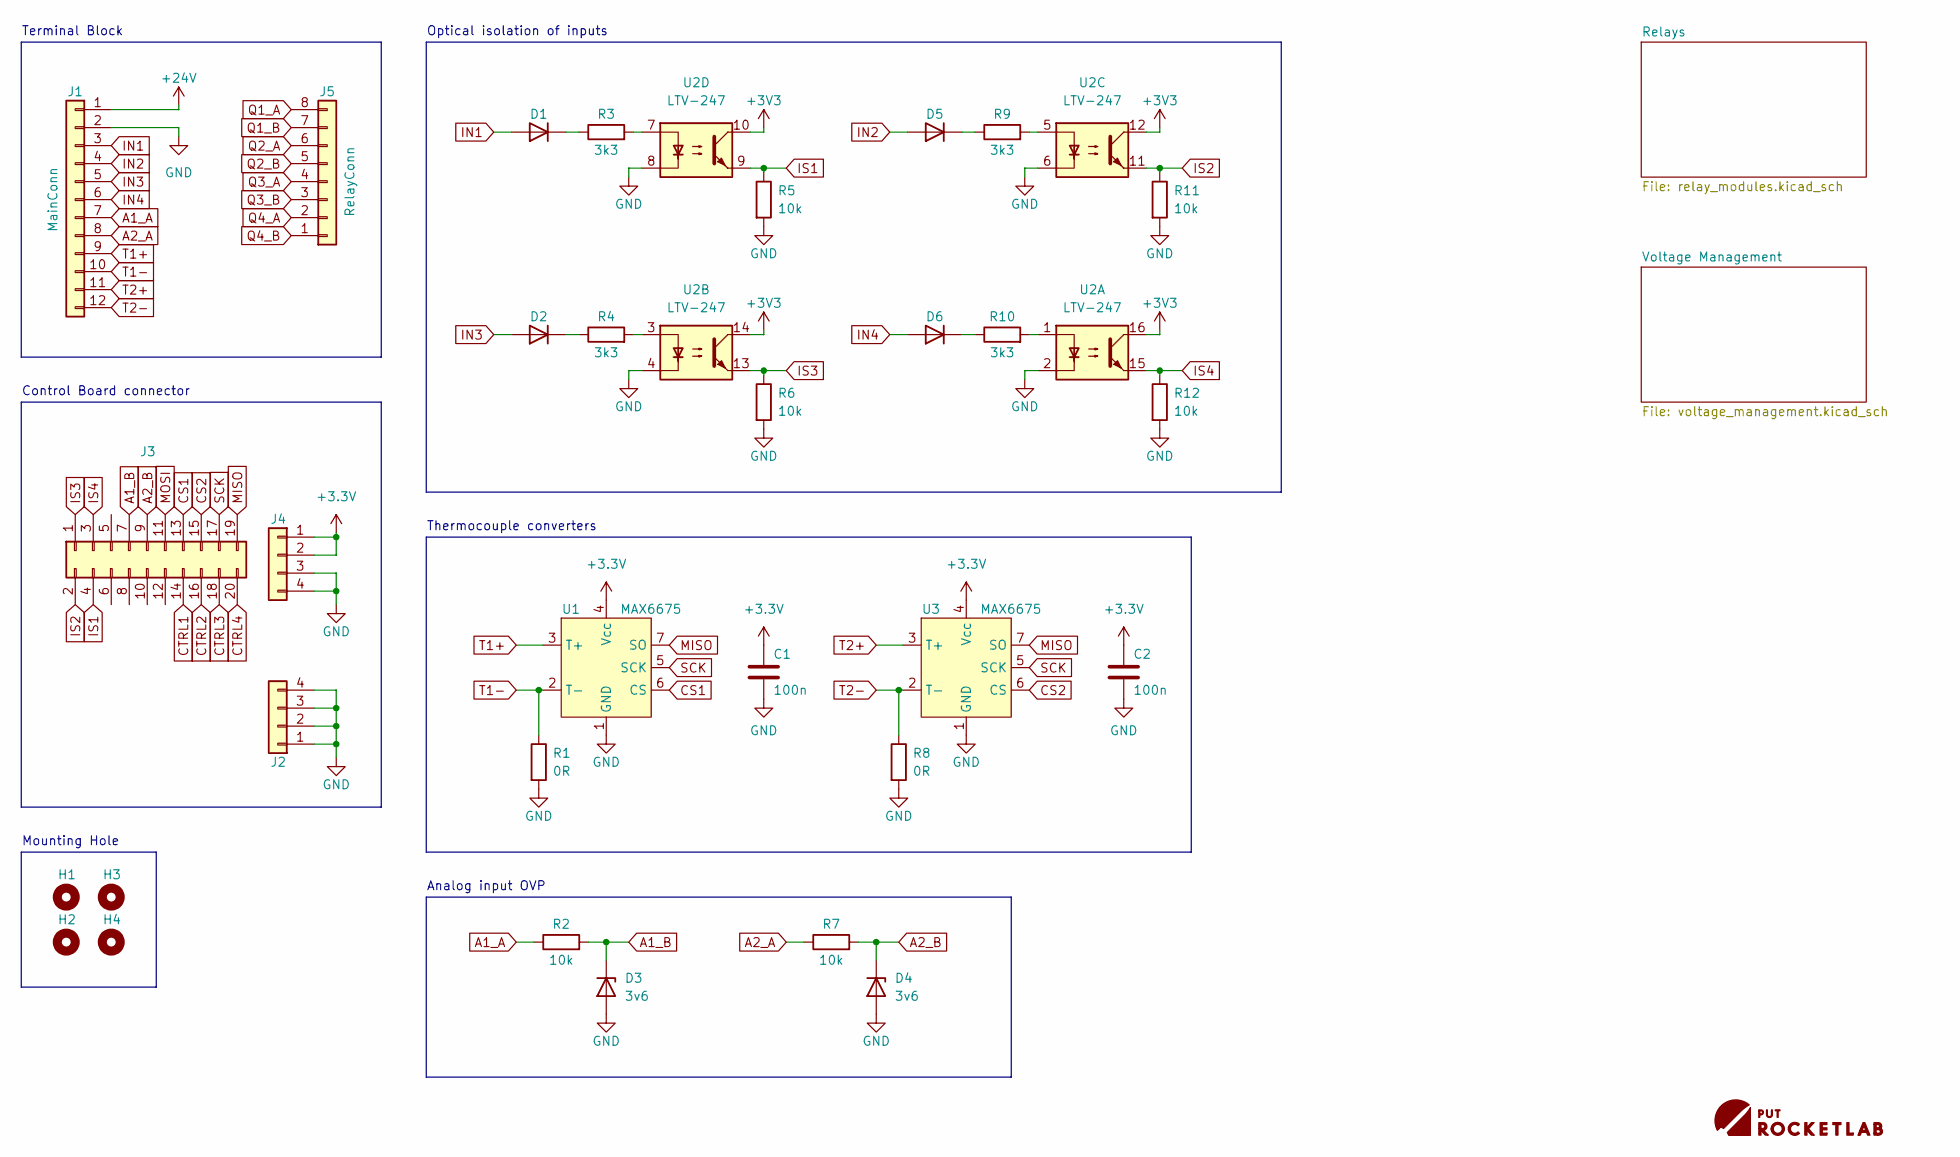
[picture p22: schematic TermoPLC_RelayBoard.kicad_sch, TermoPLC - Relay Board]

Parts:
C1, C2: 100n; C_0603_1608Metric_Pad1.08x0.95mm_HandSolder
D1, D2, D5, D6: D; D_MiniMELF
D3, D4: 3v6; D_SOD-123
G1: PutRocketLab_logo_large; PutRocketlab_logo_2_h4mm
H1, H2, H3, H4: M3; MountingHole_3.2mm_M3
J1: MainConn; TerminalBlock_RND_205-00055_1x12_P5.00mm_Horizontal
J2, J4: Conn_01x04; PinSocket_1x04_P2.54mm_Vertical
J3: Conn_02x10_Odd_Even; PinSocket_2x10_P2.54mm_Vertical
J5: RelayConn; TerminalBlock_RND_205-00073_1x08_P7.50mm_Horizontal
R1, R8: 0R; R_0603_1608Metric_Pad0.98x0.95mm_HandSolder
R2, R5, R6, R7, R11, R12: 10k; R_0603_1608Metric_Pad0.98x0.95mm_HandSolder
R3, R4, R9, R10: 3k3; R_1206_3216Metric_Pad1.30x1.75mm_HandSolder
U1, U3: MAX6675; PowerIntegrations_SO-8
U2: LTV-247; SOP-16_4.4x10.4mm_P1.27mm

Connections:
+24V: J1.1; also elsewhere on the board
A1_A: J1.7, R2.1
A1_B: D3.1 (K), J3.7, R2.2
A2_A: J1.8, R7.1
A2_B: D4.1 (K), J3.9, R7.2
CS1: J3.13, U1.6 (CS)
CS2: J3.15, U3.6 (CS)
CTRL1: J3.14; also elsewhere on the board
CTRL2: J3.16; also elsewhere on the board
CTRL3: J3.18; also elsewhere on the board
CTRL4: J3.20; also elsewhere on the board
GND: C1.2, C2.2, D3.2 (A), D4.2 (A), J1.2, J2.1, J2.2, J2.3, J2.4, J4.3, J4.4, R1.2, R5.2, R6.2, R8.2, R11.2, R12.2, U1.1 (GND), U2.2, U2.4, U2.6, U2.8, U3.1 (GND); also elsewhere on the board
IN1: D1.2 (A), J1.3
IN2: D5.2 (A), J1.4
IN3: D2.2 (A), J1.5
IN4: D6.2 (A), J1.6
IS1: J3.4, R5.1, U2.9
IS2: J3.2, R11.1, U2.11
IS3: J3.1, R6.1, U2.13
IS4: J3.3, R12.1, U2.15
MISO: J3.19, U1.7 (SO), U3.7 (SO)
MOSI: J3.11
unnamed: D1.1 (K), R3.1
unnamed: D2.1 (K), R4.1
unnamed: D5.1 (K), R9.1
unnamed: D6.1 (K), R10.1
unnamed: R3.2, U2.7
unnamed: R4.2, U2.3
unnamed: R9.2, U2.5
unnamed: R10.2, U2.1
Q1_A: J5.8; also elsewhere on the board
Q1_B: J5.7; also elsewhere on the board
Q2_A: J5.6; also elsewhere on the board
Q2_B: J5.5; also elsewhere on the board
Q3_A: J5.4; also elsewhere on the board
Q3_B: J5.3; also elsewhere on the board
Q4_A: J5.2; also elsewhere on the board
Q4_B: J5.1; also elsewhere on the board
SCK: J3.17, U1.5 (SCK), U3.5 (SCK)
T1+: J1.9, U1.3 (T+)
T1-: J1.10, R1.1, U1.2 (T-)
T2+: J1.11, U3.3 (T+)
T2-: J1.12, R8.1, U3.2 (T-)

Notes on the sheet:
Terminal Block
Analog input OVP
Control Board connector
Thermocouple converters
Mounting Hole
Optical isolation of inputs

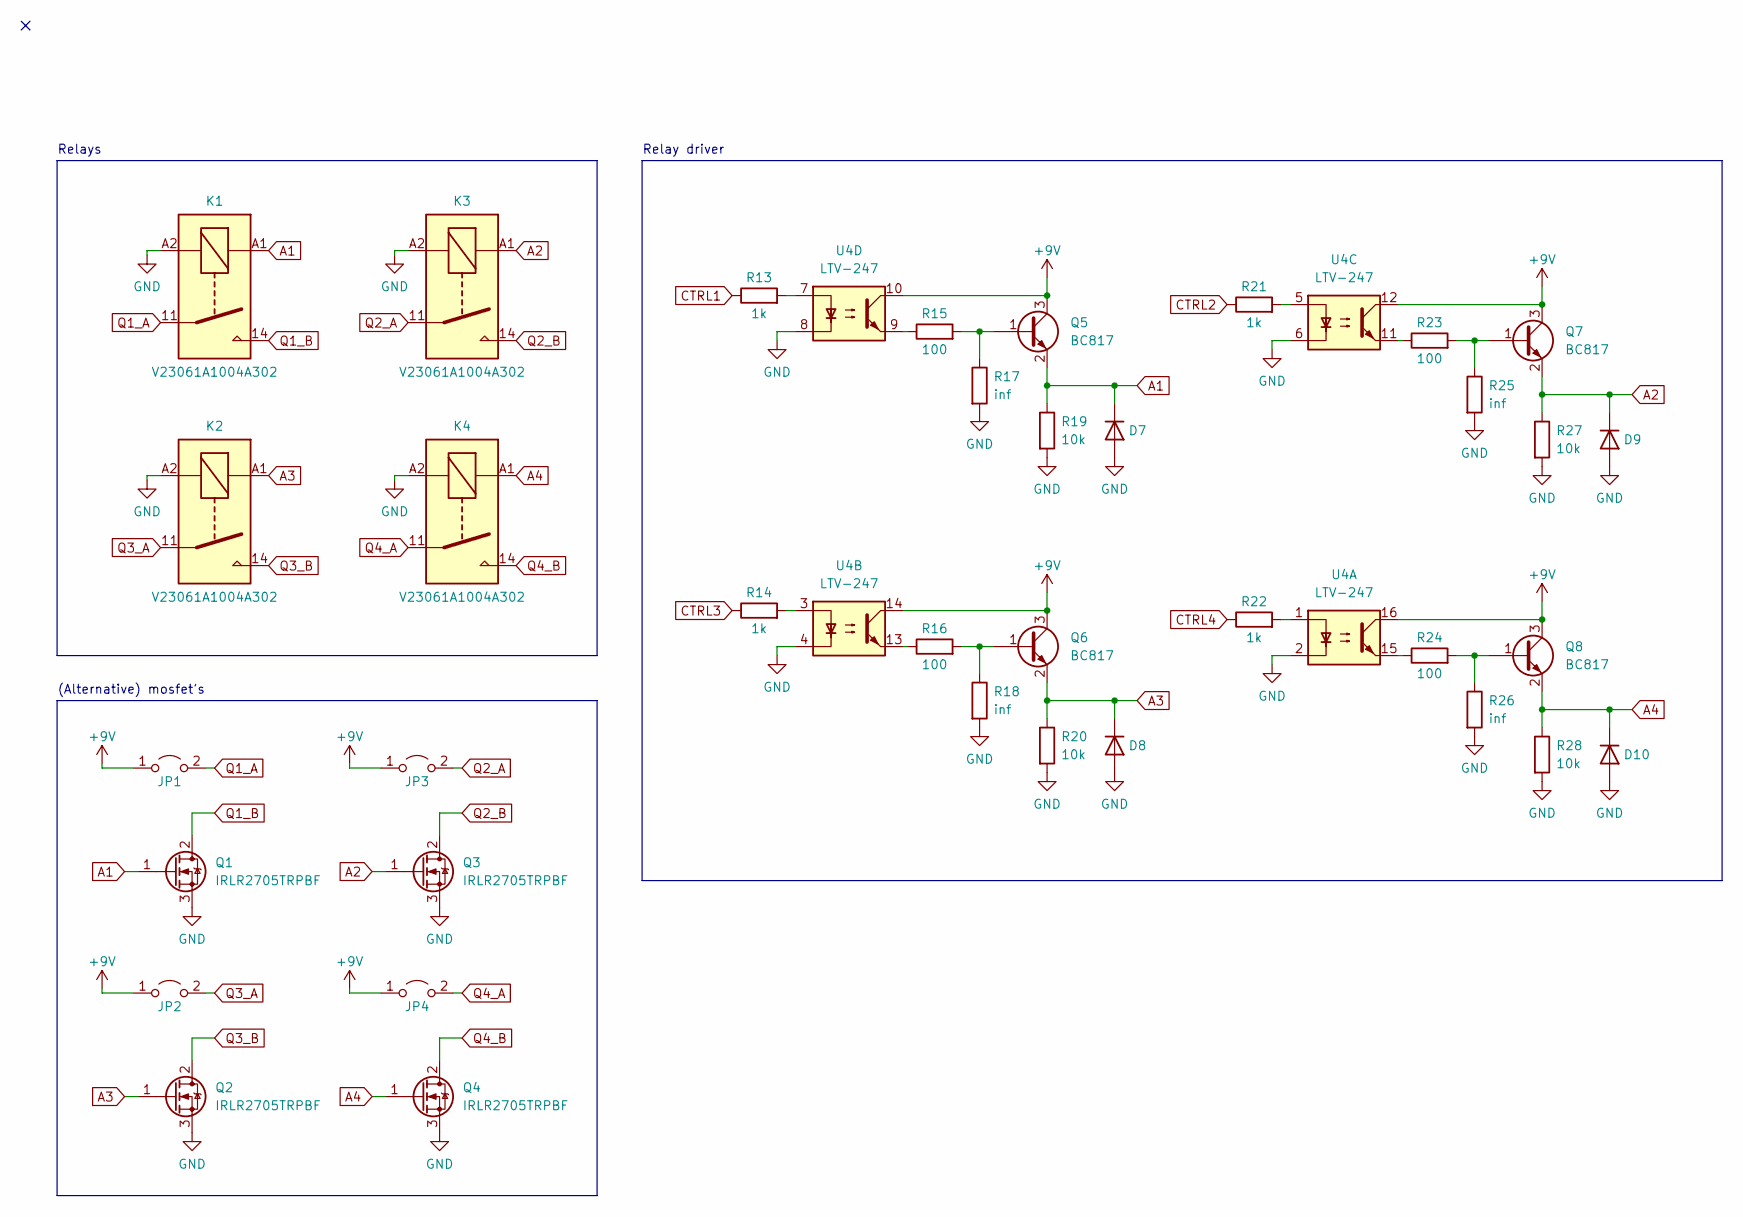
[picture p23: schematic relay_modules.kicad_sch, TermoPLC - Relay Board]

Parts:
D7, D8, D9, D10: D; D_MiniMELF
JP1, JP2, JP3, JP4: Shorted in mosfet mode; R_0603_1608Metric_Pad0.98x0.95mm_HandSolder
K1, K2, K3, K4: V23061A1004A302; V23061-A1004-A302
Q1, Q2, Q3, Q4: IRLR2705TRPBF; TO-252-2
Q5, Q6, Q7, Q8: BC817; SOT-23
R13, R14, R21, R22: 1k; R_0603_1608Metric_Pad0.98x0.95mm_HandSolder
R15, R16, R23, R24: 100; R_0603_1608Metric_Pad0.98x0.95mm_HandSolder
R17, R18, R25, R26: inf; R_0603_1608Metric_Pad0.98x0.95mm_HandSolder
R19, R20, R27, R28: 10k; R_0603_1608Metric_Pad0.98x0.95mm_HandSolder
U4: LTV-247; SOP-16_4.4x10.4mm_P1.27mm

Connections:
+9V: JP1.1 (A), JP2.1 (A), JP3.1 (A), JP4.1 (A), Q5.3 (C), Q6.3 (C), Q7.3 (C), Q8.3 (C), U4.10, U4.12, U4.14, U4.16; also elsewhere on the board
A1: D7.1 (K), K1.A1, Q1.1 (G), Q5.2 (E), R19.1
A2: D9.1 (K), K3.A1, Q3.1 (G), Q7.2 (E), R27.1
A3: D8.1 (K), K2.A1, Q2.1 (G), Q6.2 (E), R20.1
A4: D10.1 (K), K4.A1, Q4.1 (G), Q8.2 (E), R28.1
CTRL1: R13.1; also elsewhere on the board
CTRL2: R21.1; also elsewhere on the board
CTRL3: R14.1; also elsewhere on the board
CTRL4: R22.1; also elsewhere on the board
GND: D7.2 (A), D8.2 (A), D9.2 (A), D10.2 (A), K1.A2, K2.A2, K3.A2, K4.A2, Q1.3 (S), Q2.3 (S), Q3.3 (S), Q4.3 (S), R17.2, R18.2, R19.2, R20.2, R25.2, R26.2, R27.2, R28.2, U4.2, U4.4, U4.6, U4.8; also elsewhere on the board
unnamed: Q5.1 (B), R15.2, R17.1
unnamed: Q6.1 (B), R16.2, R18.1
unnamed: Q7.1 (B), R23.2, R25.1
unnamed: Q8.1 (B), R24.2, R26.1
unnamed: R13.2, U4.7
unnamed: R14.2, U4.3
unnamed: R15.1, U4.9
unnamed: R16.1, U4.13
unnamed: R21.2, U4.5
unnamed: R22.2, U4.1
unnamed: R23.1, U4.11
unnamed: R24.1, U4.15
Q1_A: JP1.2 (B), K1.11; also elsewhere on the board
Q1_B: K1.14, Q1.2 (D); also elsewhere on the board
Q2_A: JP3.2 (B), K3.11; also elsewhere on the board
Q2_B: K3.14, Q3.2 (D); also elsewhere on the board
Q3_A: JP2.2 (B), K2.11; also elsewhere on the board
Q3_B: K2.14, Q2.2 (D); also elsewhere on the board
Q4_A: JP4.2 (B), K4.11; also elsewhere on the board
Q4_B: K4.14, Q4.2 (D); also elsewhere on the board

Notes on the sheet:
Relay driver
(Alternative) mosfet's
Relays

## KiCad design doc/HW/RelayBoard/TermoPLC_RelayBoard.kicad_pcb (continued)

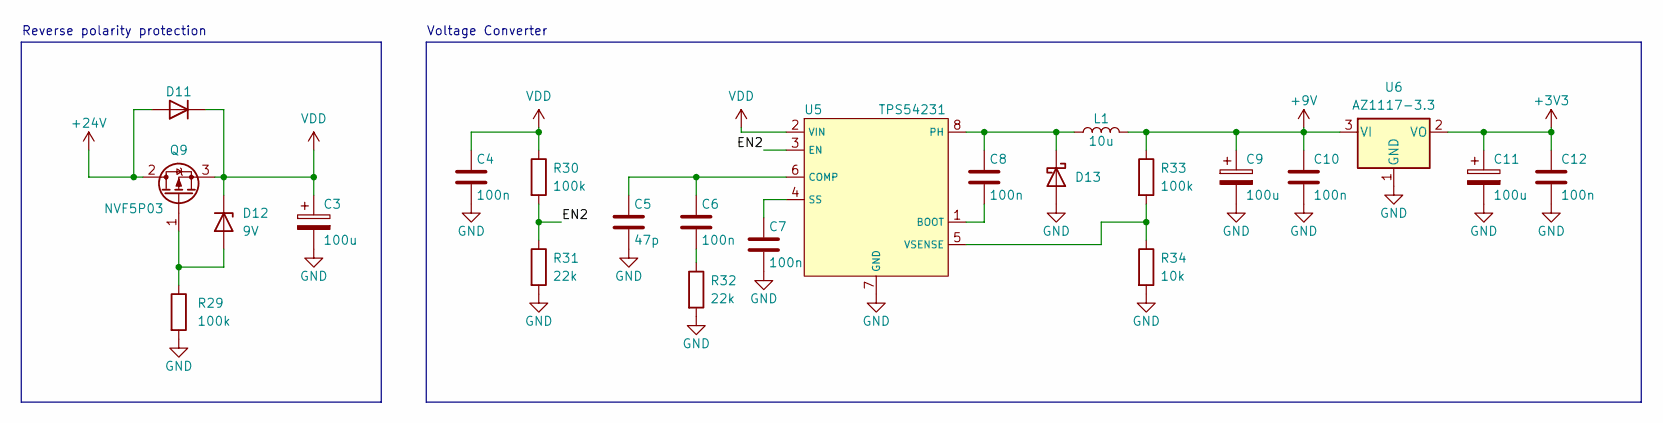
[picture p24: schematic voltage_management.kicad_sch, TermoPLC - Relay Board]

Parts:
C3, C9, C11: 100u; CP_Radial_D6.3mm_P2.50mm
C4, C6, C7, C8, C10, C12: 100n; C_0603_1608Metric_Pad1.08x0.95mm_HandSolder
C5: 47p; C_0603_1608Metric_Pad1.08x0.95mm_HandSolder
D11: D; D_MiniMELF
D12: 9V; D_SOD-123
D13: D_Schottky; D_SMA
L1: 10u; L_Bourns_SRN8040TA
Q9: NVF5P03; SOT-223-3_TabPin2
R29, R30, R33: 100k; R_0603_1608Metric_Pad0.98x0.95mm_HandSolder
R31, R32: 22k; R_0603_1608Metric_Pad0.98x0.95mm_HandSolder
R34: 10k; R_0603_1608Metric_Pad0.98x0.95mm_HandSolder
U5: TPS54231; SOIC-8_3.9x4.9mm_P1.27mm
U6: AZ1117-3.3; SOT-223-3_TabPin2

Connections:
+9V: C9.1, C10.1, L1.2, R33.1, U6.3 (VI); also elsewhere on the board
+24V: D11.2 (A), Q9.2 (D); also elsewhere on the board
/Voltage Management/EN2: R30.2, R31.1, U5.3 (EN)
GND: C3.2, C4.2, C5.2, C7.2, C9.2, C10.2, C11.2, C12.2, D13.2 (A), R29.2, R31.2, R32.2, R34.2, U5.7 (GND), U6.1 (GND); also elsewhere on the board
unnamed: C5.1, C6.1, U5.6 (COMP)
unnamed: C6.2, R32.1
unnamed: C7.1, U5.4 (SS)
unnamed: C8.1, D13.1 (K), L1.1, U5.8 (PH)
unnamed: C8.2, U5.1 (BOOT)
unnamed: D12.2 (A), Q9.1 (G), R29.1
unnamed: R33.2, R34.1, U5.5 (VSENSE)
VDD: C3.1, C4.1, D11.1 (K), D12.1 (K), Q9.3 (S), R30.1, U5.2 (VIN)

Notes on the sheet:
Reverse polarity protection
Voltage Converter

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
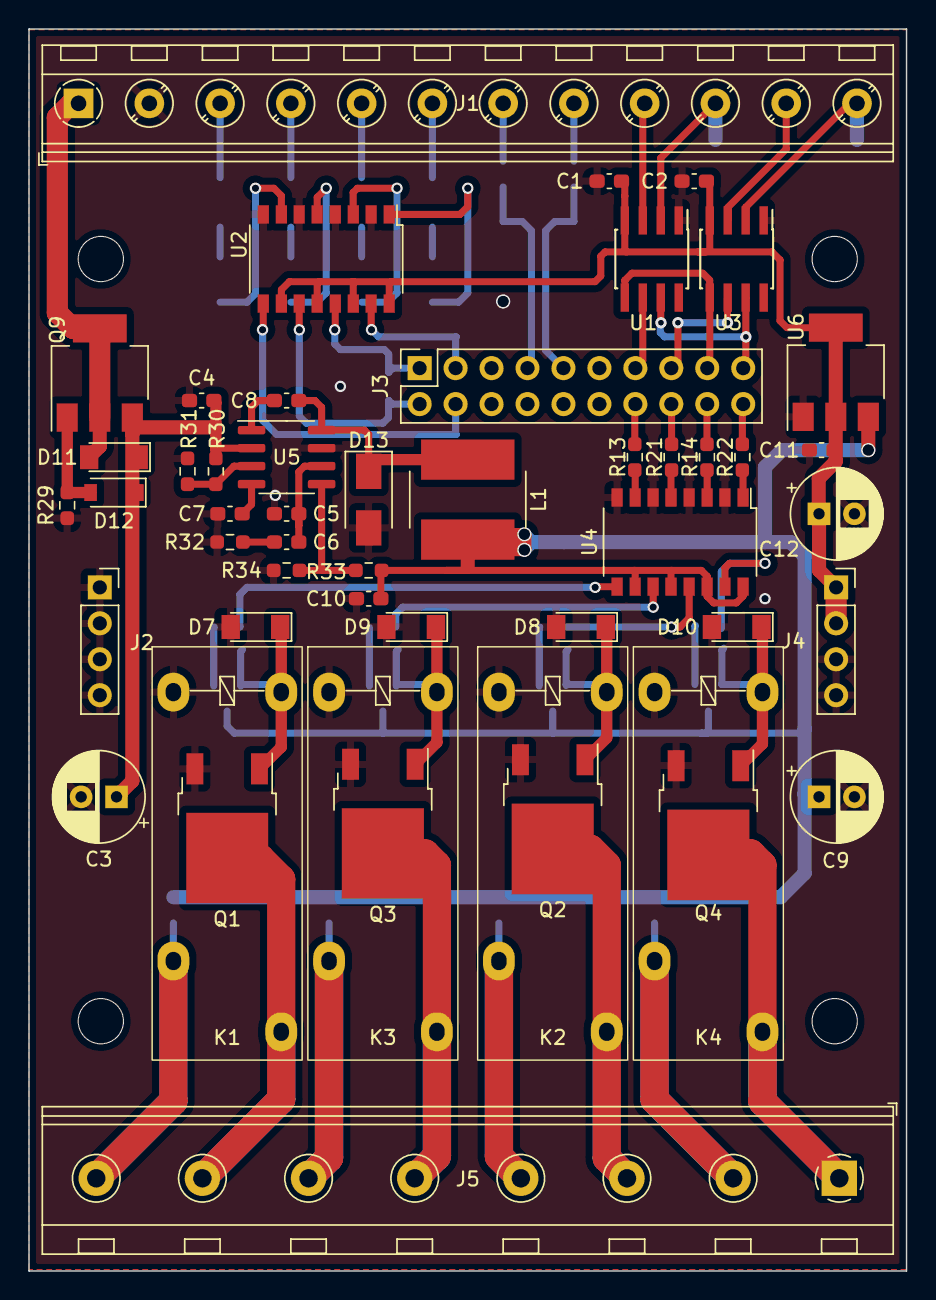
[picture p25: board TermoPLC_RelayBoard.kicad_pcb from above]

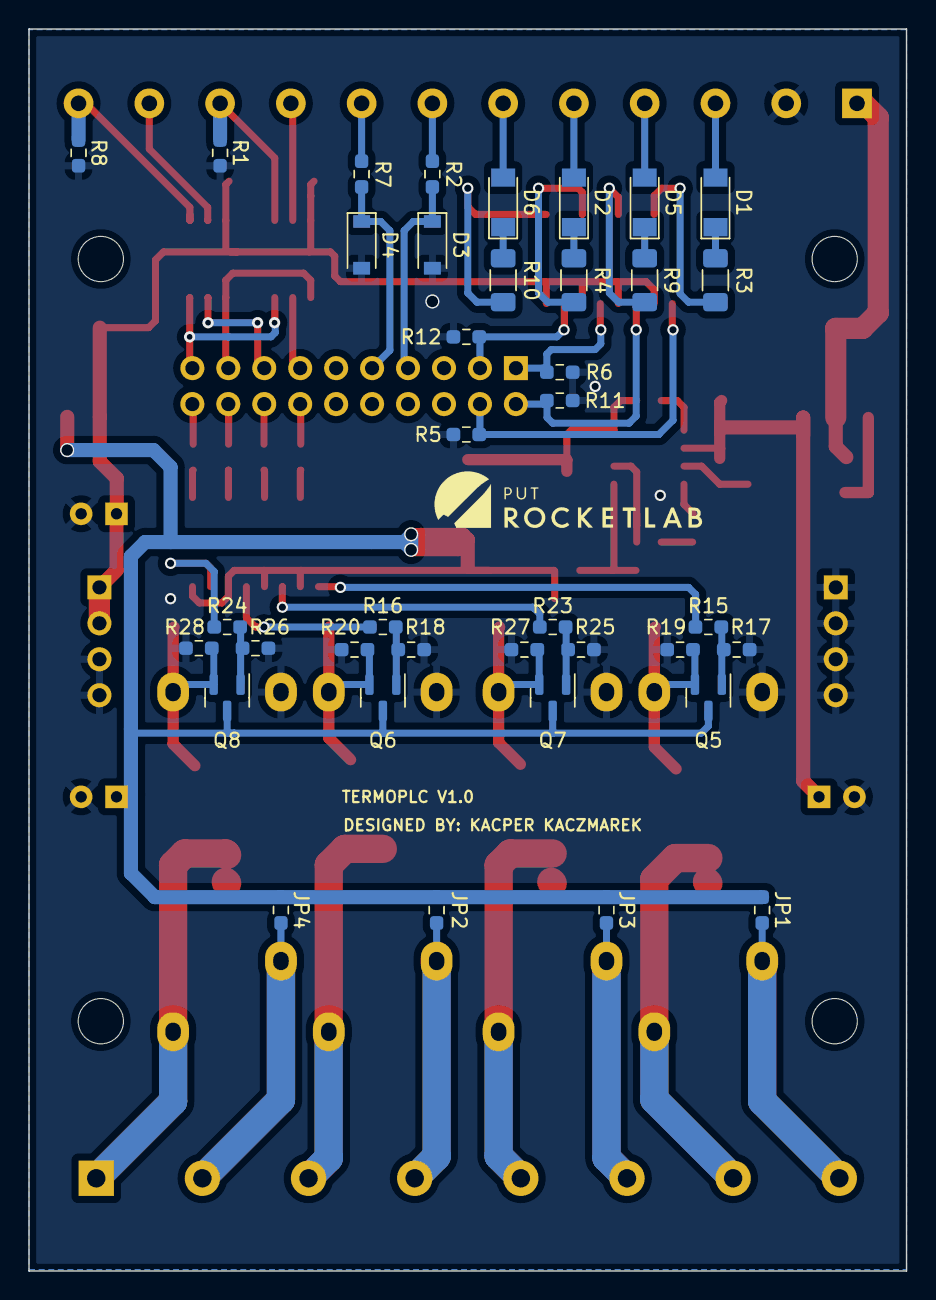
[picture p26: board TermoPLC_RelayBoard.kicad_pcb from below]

Board: 2 copper layers, 62.0 x 87.8 mm, 93 parts (39 on the bottom side), 69 nets.

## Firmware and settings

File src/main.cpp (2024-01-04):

#include "freertos/FreeRTOS.h"
#include "freertos/task.h"

#include "global_config.h"
#include "logger.h"

#include "system_manager_task.h"
#include "ui_manager_task.h"
#include "sd_manager_task.h"
#include "wifi_manager_task.h"
#include "server_manager_task.h"
#include "profile_manager_task.h"
#include "regulator_manager_task.h"


static const char * const TAG = "MAIN";


// main must be C function
#ifdef __cplusplus
extern "C" {
#endif


void app_main(void)
{
    // default log level at at startup
    esp_log_level_set("*", DEFAULT_LOG_LEVEL);
    TB_LOGI(TAG, "Start");

    // start System Manager Task
    xTaskCreatePinnedToCore(systemManagerTask, "SysMgr", 4096, NULL, 1, NULL, 1);

    // start UI Manager Task
    xTaskCreatePinnedToCore(uiManagerTask, "UIMgr", 4096, NULL, 1, NULL, 1);

    // start SD Manager Task
    xTaskCreatePinnedToCore(sdManagerTask, "SDMgr", 10240, NULL, 1, NULL, 0);

    // start WiFi Manager Task
    xTaskCreatePinnedToCore(wifiManagerTask, "WiFiMgr", 4096, NULL, 1, NULL, 0);

    // start Profile Manager Task
    xTaskCreatePinnedToCore(profileManagerTask, "ProfMgr", 4096, NULL, 1, NULL, 1);

    // start Server Manager Task
    xTaskCreatePinnedToCore(serverManagerTask, "ServMgr", 10240, NULL, 1, NULL, 0);

    // start Regulator Manager Task
    xTaskCreatePinnedToCore(regulatorManagerTask, "RegMgr", 4096, NULL, 1, NULL, 1);

    // end Main task
    vTaskDelete(NULL);
}


#ifdef __cplusplus
}
#endif

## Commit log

2023-10-25 add documentation
    [Accessories.kicad_sch, Nokia_5110_LCD.kicad_sch, TermoPLC_ControlBoard.kicad_pcb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]
2023-10-25 change to C++23, add basic buzzer driver
2023-10-26 move drivers to separate component, fix: mismatched delete
2023-10-27 add gpio expander driver set pin mode, i2c wrapper
2023-10-28 add GPIOExpander interrupt handling
2023-10-28 fix: set pin mode only on port0, change: intr to falling edge
2023-10-28 add pin change detect, pca9539 utility macros
2023-11-03 add: button, expander controller class
2023-11-04 add short/long press, fix port bug pca9539 driver
2023-11-04 button callbacks on API layer
    [Accessories.kicad_sch, Nokia_5110_LCD.kicad_sch, TermoPLC_ControlBoard.kicad_pcb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]
2023-11-04 add timer for buzzer
2023-11-05 add LCD driver with API layer
2023-11-05 add RGB leds driver
2023-11-05 update SW architecture schematic
2023-11-13 add SD driver, improve commands
2023-11-17 improve sd mount/unmount
2023-11-18 init wifi driver, remove ugly externs
2023-11-25 add partitions table
    [partitions.csv]
2023-11-26 add profile manager, profile manager task, profile queue, some commands, profile class with timer, profile load, run and end
2023-12-01 add: profile update timer, progress %, update event
2023-12-02 Add frame_buf handling
2023-12-03 add protobuf, nanopb, publish on profile-update topic
    [partitions.csv]
2023-12-26 Add showing current path in start profile scene
2024-01-03 Add timer to send wifi strength event
2024-01-04 Add button bindings in button.h
2024-01-04 add regulator communication layer, publish status over MQ, read uC temp
2024-01-04 WIP: new PCB software
    buzzer on GPIO expander, add GPIO expanders reset, change pinout to new HW, add MAX31865 library, add OneWire library, add relay controller, fix expander interrupts on port 1, add SPI3 semaphore, temporarly commented out LCD
2024-01-12 Add buzzer when profile ended and on button press
2024-01-27 regulator from tests
